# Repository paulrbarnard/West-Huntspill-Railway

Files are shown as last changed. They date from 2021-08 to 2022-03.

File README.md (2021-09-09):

# West-Huntspill-Railway
This is a project for the West Huntspill Model Railway

https://en-gb.facebook.com/pages/category/Arts---Entertainment/West-Huntspill-Railway-246006162152817/

WHR run model live steam and electric locos on their track.

This project was to replace the old signal system with something a little more flexible
The key modules are the SignalBox which provides the control logic with a track display
and the sensor/lights module that detects the trains and switches the signal lights.

PCB layouts are included in the PCB folder in KiCAD format. Parts lists and UK suppliers are in the excel files in the PCB section.

An overview manual is contained in the .docx file

The PCB layouts and code are released free of charge and can be used or modified in any way you like.

No expressed or implied warrenty or gaurentee is made.

If you like the project and make use of it consider a donation to the West Huntspill Model Railway

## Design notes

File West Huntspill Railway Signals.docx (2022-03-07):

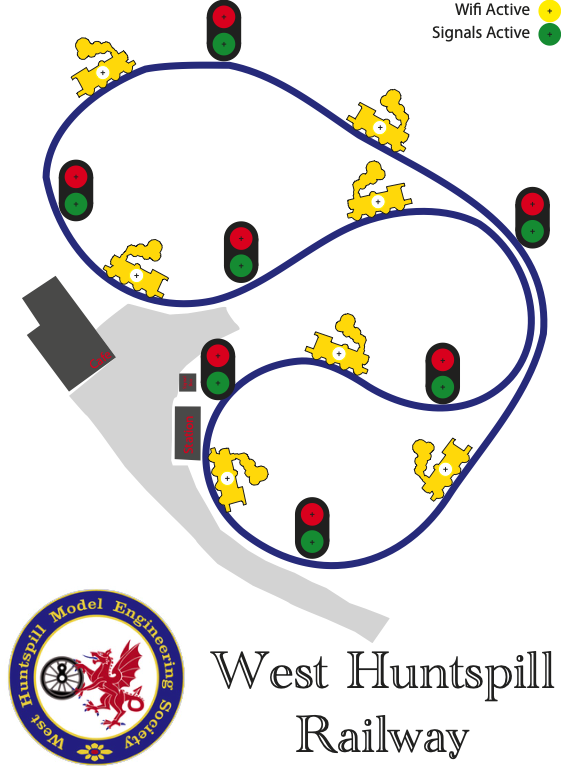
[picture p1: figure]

Signalling

## Signal Box Module

The signal box module is the main controller for the signals around the track. It has two modes of operation, master and slave.

Master mode enables the main processing of the signal box. Messages are received from the sensor modules and the appropriate light changes determined. The light status is then sent to all the sensor modules. In master mode the signal box module can support up to 16 signals.

Slave mode permits the addition of extra track display units showing the location of trains and the state of the signals. When in slave mode the signal box displays the status of the signals and track sections. The number of slave signal box modules is essentially unlimited. Total devices on the network is limited to 200 units.

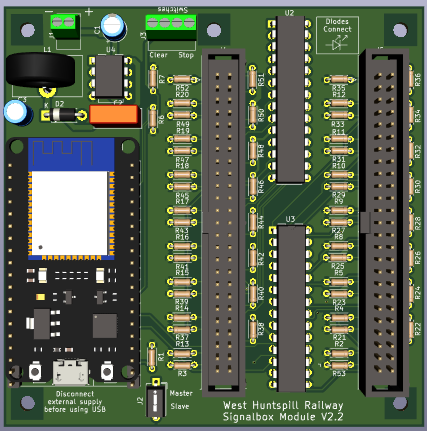
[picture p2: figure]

Figure 1 top view of the signal box pcb

### Power Supply

The signal box module runs from a DC power supply with a voltage between 6 and 24V with a maximum power draw of 1W. Power is connected to the 2 pin screw terminal (J1) on the PCB. Care must be taken to connect the power supply with the correct polarity. Failure to do so can result in damage to the module.

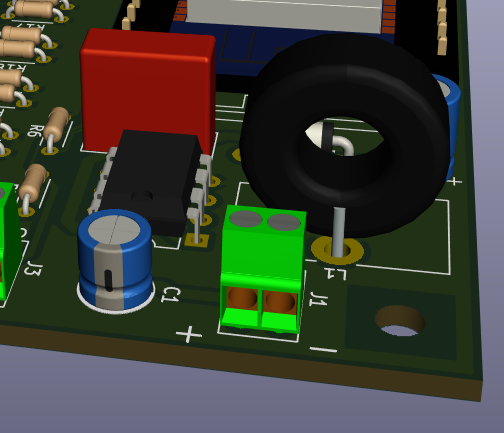
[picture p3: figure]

Figure 2 power connection

### Controls

The signal box module is equipped with two connections for switches to control the signals on the track. Buttons are connected to the 4 pin screw terminal (J3) on the PCB. A “Stop” button, typically a latching button, is used to turn all signals to RED. This would typically be used in an emergency stop situation. A “Clear” button, usually a momentary button, is used to clear all the yellow trains from the track. This is used to clear a “Ghost Train” from a track section if for example it has been removed at the transfer area.

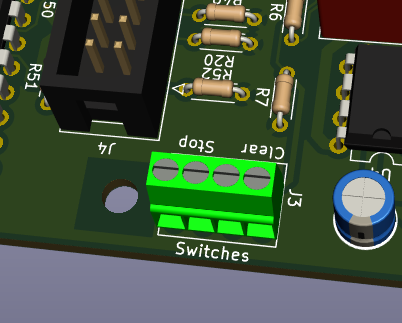
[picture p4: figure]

Figure 3 switch connections

### Indicators

The signal box module has up to 16 red and green LEDs representing the signals on the track. These are matched by up to 16 yellow LEDs indicating an occupied section of track. There is also a yellow “WiFi Active” LED indicating that the signal box module is connected to WiFi and a green “Signals Active” LED indicating that the signal box module is connected to sensor modules and actively controlling the signals. When in Demo mode the Active LED flashes. When in Slave mode the Active LED remains off.

### Typical construction

The typical construction for a signal box module consists of a printed face plate showing the layout and position of the signals with the train LEDs spaced between the signals

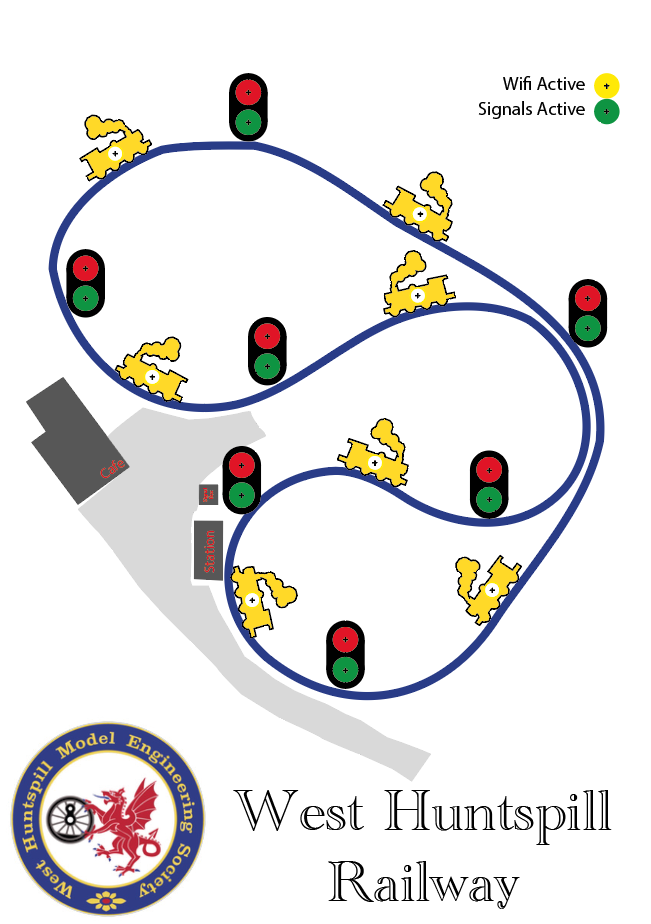
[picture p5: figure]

Figure 4 Typical face plate design

The LEDs are connected via ribbon cable to the signal box module.

### Indicators

The LEDs are connected in groups of three starting at trace one of the ribbon cable. The LED colour sequence is GREEN, RED, YELLOW. The final LED on J4 is YELLOW for the WiFi indication and the final LED on J5 is GREEN for the active indication (note making the WiFi and active LED the same colour would permit a standard cable construction)

The Cathode (+’ve) of the LED connects to the first wire and the Anode (-‘ve) to the next wire in the cable.

The first six traces of the ribbon cable connected to J4 have the indicators for the first track section 0. The first six traces of the ribbon cable connected to J5 have the indicators for section 8.

Populate as many indicators as required for the signals deployed on the track. Fully populating the ribbon cables and leaving the unused indicators inside the signal box case permits simple addition of extra signals indicators in the future.

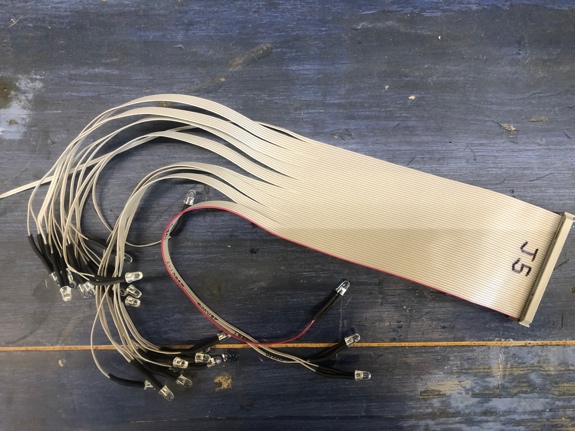
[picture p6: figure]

Figure 5 indicators attached to ribbon cable

### Operation

Power on the signal box module. The WiFi active LED indicator will light when the WiFi is connected. Note: The WiFi can be provided by one of the sensor modules (selectable via jumper on the sensor module). This is suitable for small deployments only and limited to six active devices on the network. For larger layouts an external WiFi network is required. Once WiFi is connected the signal box will listen for sensors to connect. When one or more sensors has connected the signal box module will enter active mode and start controlling the signals. The signals active indicator will light.

Any inactive sensors will be ignored and operation will continue with only the active signals.

It is possible to simply turn the power on for all the sensors and signal box modules to start the signals working.

### Emergency Stop

Press the Stop button and all the signals will be set to RED. Release the Stop button and automatic mode will resume. Any trains that have moved while the Stop mode is enabled will be indicated in their new positions once the Stop button is release.

### Clear Track

Pressing the clear button will remove all the yellow track occupied indicators from the board. Red signals (blocking access to previously occupied track) will remain RED and may be cleared by pressing and releasing the Stop button momentarily.

### Demo Mode

The sensor module has a demo/test mode. This simulates a train travelling around the track switching signals to red and making track occupied. Slave signal box modules and the signals will also indicate the simulated train travel.

Demo mode is started by pressing the stop button and the clear button when the master signal box module is powered on. Hold the clear button down as the train advances around the track until it reaches the final section (when Signal 6 goes red in the example below). Release the clear button to let the signal box know how many sections are included in the demo. The demo mode will continue with the train looping around the track until the stop button is released. When the stop button is released the signal box will enter the normal operating mode.

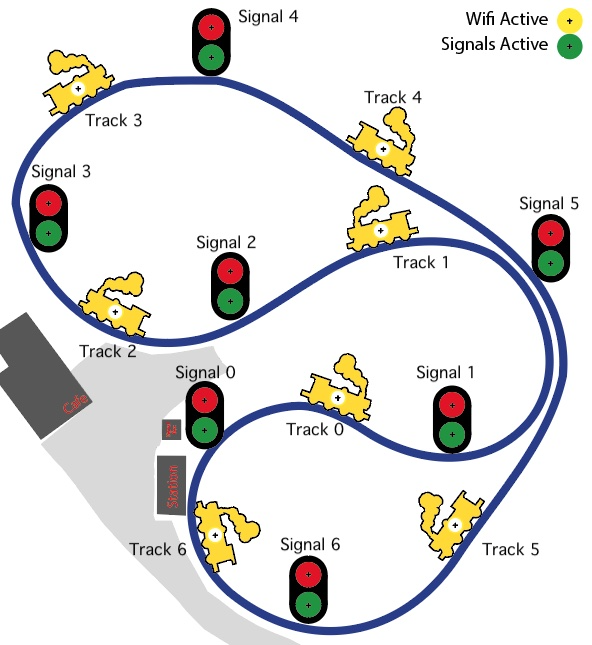
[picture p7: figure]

Figure 6 Indicator detail

## Sensor Module

The sensor module provides multiple functions and great flexibility in layout and use. The sensor module uses an ultra-sonic range sensor to detect the presence of a train. The sensor has a maximum range of 4m and a sensor beam width of 15 degrees. The sensor should be positioned such that a train travelling along the track passes through the ultra-sonic beam. The sensor range is adjustable to eliminate false detection such as from a person walking between the track and the sensor or along the outside of the track.

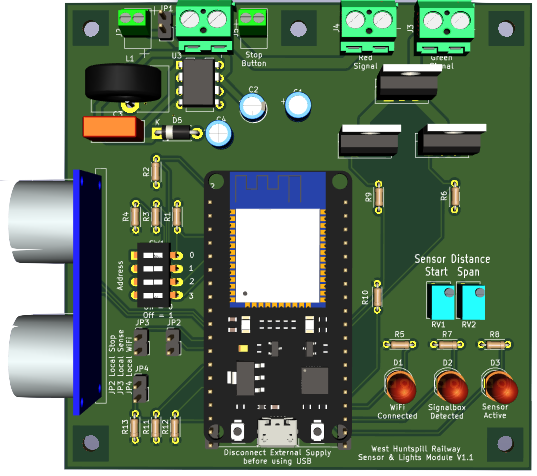
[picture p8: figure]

Figure 7 Sensor module

The sensor module supports a stop button that can be used to turn the signal to red manually. This permits the control of the signal by the station master or steaming bay manager to control departure of trains from the station or to prevent access to the transfer area when trains are being staged. There are two high current capable outputs for connection to the signal lights. The sensor modules are also capable of providing the WiFi network for the system.

### Power Supply

The sensor module has flexible power supply options. It is possible to use different power supplies for the module and the signal lights. This provides more options of lights types, including the possibility of switching motors or solenoids to control functions such as gates, barriers or bells.

If a single supply is to be used a jumper is connected to JP1 and power connected to J1

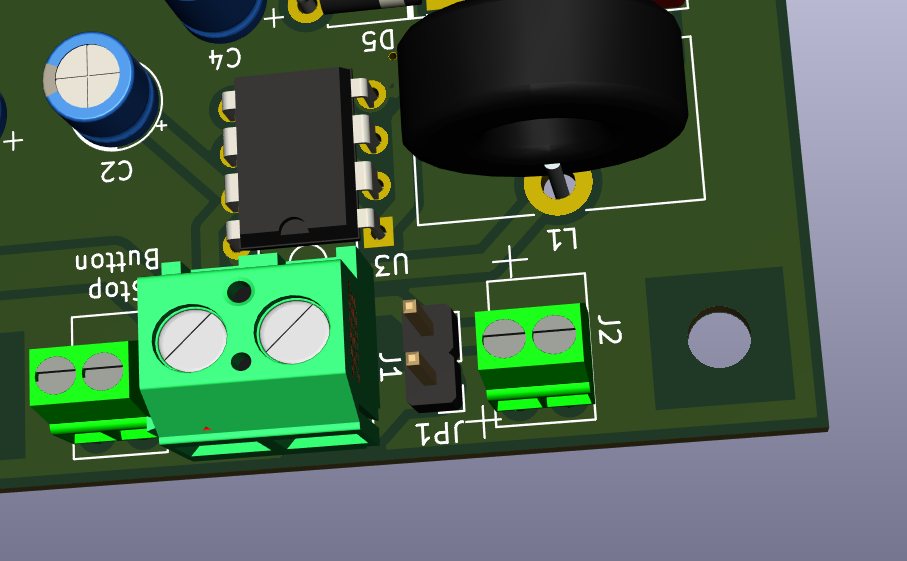
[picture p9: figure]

Figure 8 Power connection

#### Board Power

Connector J2 is used for board power and supports voltages of 6 to 24V DC. Care must be taken to ensure correct polarity of the power connection. Incorrect connection can damage the sensor module.

#### Signal Power

Connector J1 is used for the signal lights power and supports voltages from 6 to 60V. The sensor module switches can handle 50A maximum but require additional heat sinks for currents over 10A. If inductive loads (motors, solenoids, relays etc) are connect then the protection diode D4 (DSSK50-01A) must be fitted.

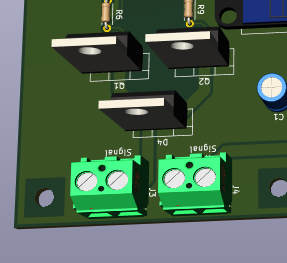
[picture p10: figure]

Figure 9 Location of protection diode

Important! If JP1 is fitted the signal power must not exceed 24V or damage to the sensor module will occur.

### Signal Connections

The signal lights are connected to J3 (green) and J4 (red). If LED lights are used ensure the polarity of connection is correct.

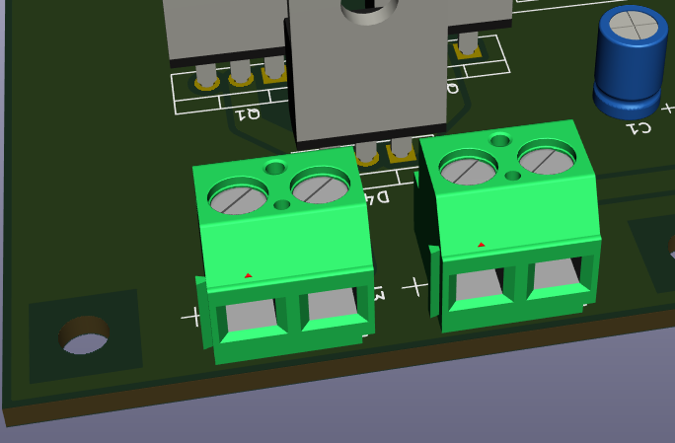
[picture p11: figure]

Figure 10 Signal light connectors

### Stop button

An optional stop button can be connected to the sensor module. This permits the manual control of the signal from the signal location. A typical use is at the station where a stop button can be used by the station master to control the departure of trains. Wire connections to the stop button should be limited in length to ensure reliability. As a rule of thumb 10m should be OK. In the case where the stop button needs to be at a greater distance (possibly at the transfer area) an additional sensor module can be used as a remote stop button Configuration

#### Address

Each sensor module needs to be assigned an address. This corresponds to its position in the signal sequence around the track, see Figure 6 Indicator detail for a typical addressing sequence for a track.

Addresses are set using SW1

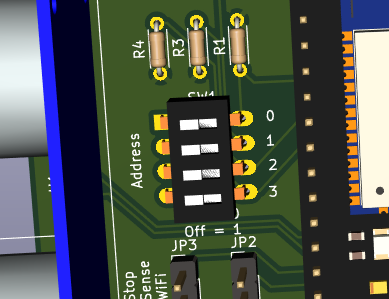
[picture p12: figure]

Figure 11 Address switch showing set to address 15

The following table shows the switch settings for all possible addresses.

Sensor | SW1-0 | SW1-1 | SW1-2 | SW1-3
0 | ON | ON | ON | ON
1 | OFF | ON | ON | ON
2 | ON | OFF | ON | ON
3 | OFF | OFF | ON | ON
4 | ON | ON | OFF | ON
5 | OFF | ON | OFF | ON
6 | ON | OFF | OFF | ON
7 | OFF | OFF | OFF | ON
8 | ON | ON | ON | OFF
9 | OFF | ON | ON | OFF
10 | ON | OFF | ON | OFF
11 | OFF | OFF | ON | OFF
12 | ON | ON | OFF | OFF
13 | OFF | ON | OFF | OFF
14 | ON | OFF | OFF | OFF
15 | OFF | OFF | OFF | OFF

When using multiple sensor modules for a single section of track set all the modules to the same address

### Local Jumpers

The three local jumpers permit configuration of the board characteristics.

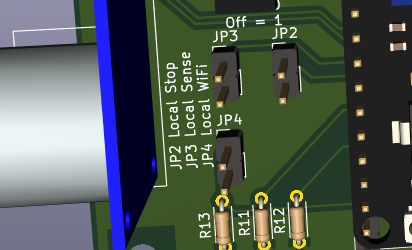
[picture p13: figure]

Figure 12 Local configuration jumpers

#### Local WiFi

When JP4 is shorted the sensor module will create a WiFi network for the signals. Only one sensor module, usually the one closest to the centre of the area, is configured to provide the WiFi network.

Note: Local WiFi only supports six connected devices. For larger networks of devices and external WiFi device is required.

#### Local Stop

JP2 is used to configure the operation of the stop switch. When the jumper is not fitted the presence of a train on the track is determined by the train sensor. When JP2 is shorted releasing the stop switch will force clear the track. Typical use of the forced clear option is at the Steaming Bay where trains are removed from the track. Releasing the stop button will clear the track and set the signals to green. Alternatively at the Station, configured without the short, releasing the stop button will cause the red signal to flash if a train is still occupying the track after the light. This lets the station master know that he/she has released the stop but it is not safe for the train to depart.

Note: an additional sensor module can be used to support the stop button. The signal light switching will also function on the additional module enabling local tally lights to be connected to the remote sensor module. This is useful if the main signal lights are not visible from the stop button location.

#### Local Sense

JP3 is used to disable the sensor distance settings on the board. When shorted the sensor will take the sensor range settings sent by the signal box. This permits the use of the WHRDisplay application to configure the sensor settings.

### Train Sensor setup

The ultra-sonic train sensor can be configured to avoid false detection. Two adjustment screws are provided.

RV1 is used to set the minimum detection distance. RV2 sets the span of the detection range.

Alternatively the WHRDisplay application can be used with the sensor configured for remote settings.

To adjust the range position a board between the train sensor and the track so that the board is a few centimetres closer to the sensor than any part of the train will travel. The widest part of the train is likely the legs of the driver or passengers.

Figure 13 Sensor setup method

Turn the sensor screw until the sensor active LED on the sensor module lights up. You might need to wind the screw fully one way then reverse the direction to find the detection point. Fully anti clock wise is the minimum distance. 10 full turns are required to go from end to end of the adjustment.

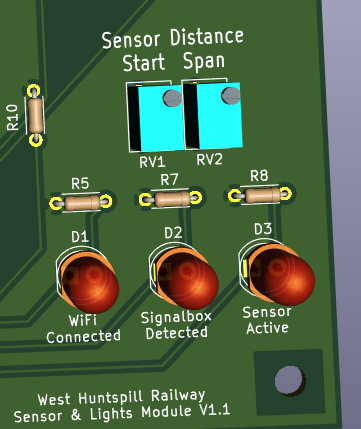
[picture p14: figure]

Figure 14 Sensor adjustment screws and sensor active LED

Reposition the board to the outside of the track and adjust the span screw until the sensor active LED just changes state.

Check the settings are correct by moving the board from the sensor position to the far side of the track and watch the sensor active LED. It should light when the board is positioned anywhere where the train is expected to travel. Walk through the sensor beam on both the inside and outside of the track to ensure that the sensor does not trigger.

Note: The sensor only registers the closest thing to the sensor. If a person or other object is blocking the path between the sensor and the track the sensor will not activate when a train passes.

#### WHRDisplay application

An iPhone, iPad and macOS application is available which displays the current track light status and displays the messages sent by the sensor modules. When adjustments to the distance are made these can be seen on the application.

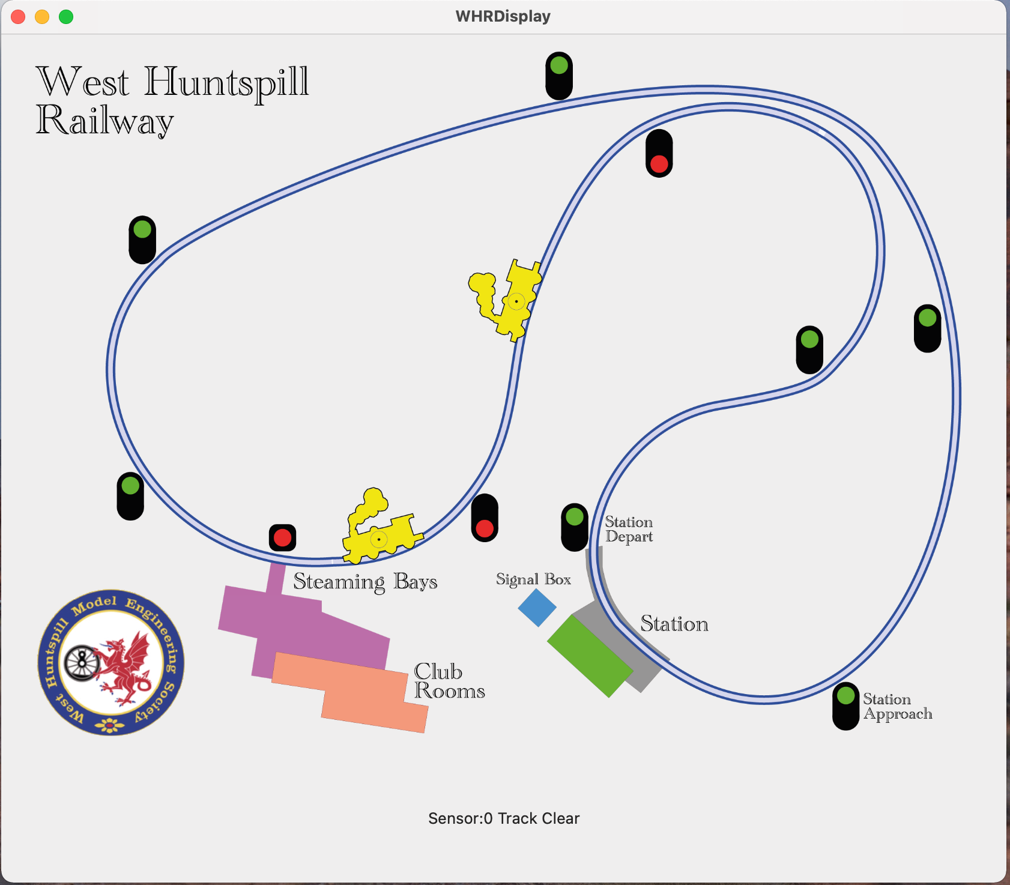
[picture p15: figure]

Figure 15 WHRDisplay application

## TP-Link Exterior WiFi

For full coverage of the WHR site an external WiFi device is provided. This is based on a TP-Link Omada Outdoor access point. The outdoor part should be mounted on the roof of the signal box or at some other convenient location. Coverage area is an approximately 200m radius. The unit has an indoor box that provides power and the network connectivity. Note: the indoor unit is a custom device built using the TP-Link power over ethernet adaptor and the main board from an GL-iNet Smart router, together with a 5V power supply. The indoor unit is installed in a 3D printed box.

The indoor unit should be located close to a Mains 240V supply. An ethernet cable connects the indoor and outdoor units. Ethernet cables up to 100m are supported.

Plugging a 4G or 5G USB dongle or smart phone supporting tethering in to the side of the indoor unit can enable the provision of wide area network connectivity for the site. This might be useful at a future date. If required at any time please contact Paul Barnard to configure a public access SSID for the network.

## Information

The source code and PCB layouts (KiCAD) for the project are available on GitHub

https://github.com/paulrbarnard/West-Huntspill-Railway.git

The PCB are laid out for ESP32 DevKitC V4. Full parts list and UK based supplier information is contained in the PCB design documents.

The ESP board will be damaged if the USB is connected at the same time as the board power supply. The board power supply must be disconnected before using the USB to program the ESP32. The ESP32DevKit devices are socketed and can be removed from the main PCB for reprogramming to eliminate the need to disconnect wiring on site.

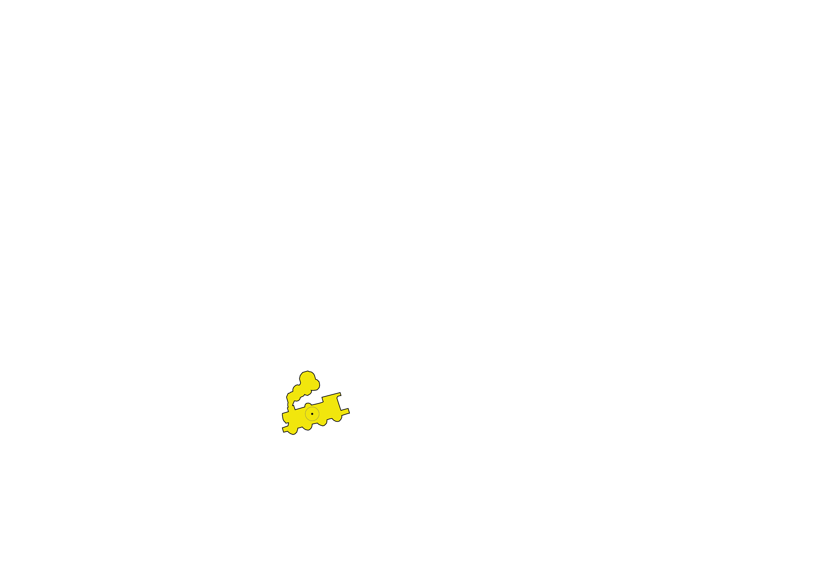
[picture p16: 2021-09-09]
Face Plate Artwork/3x/Train3@3x.png

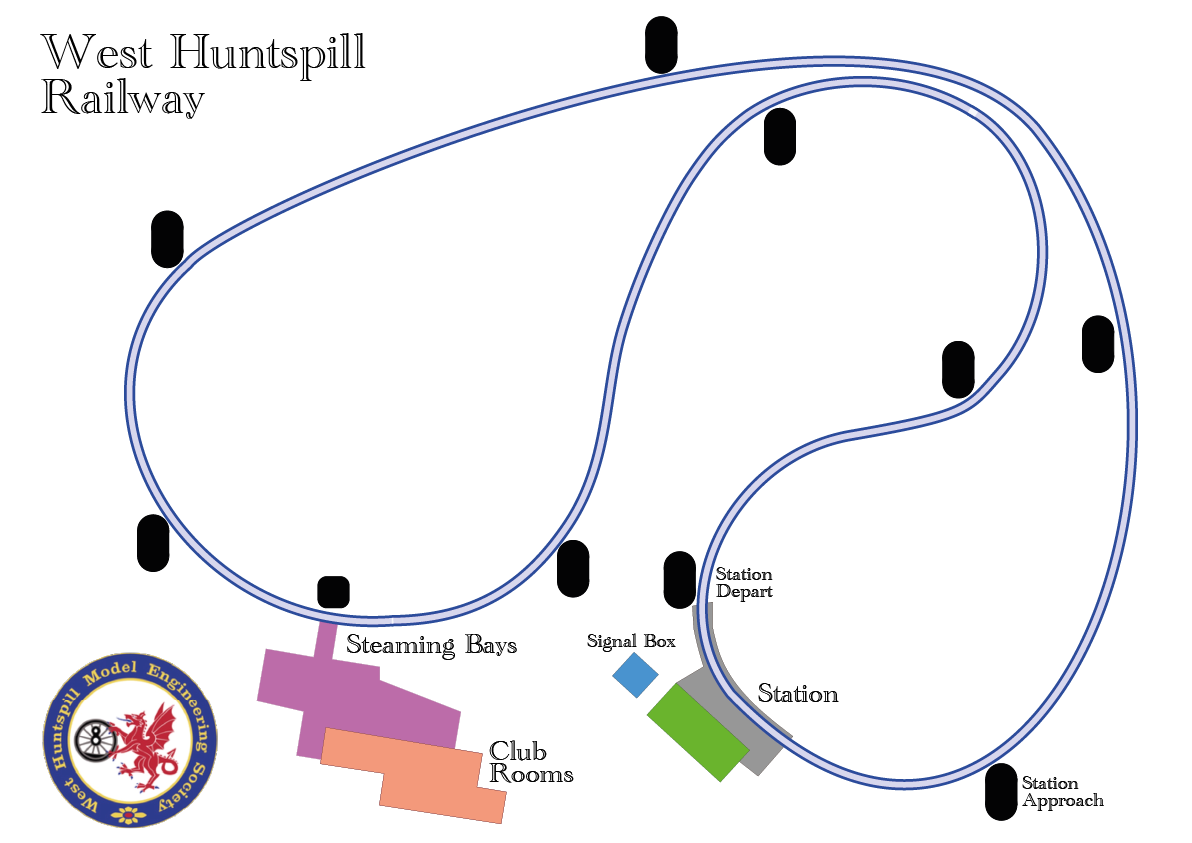
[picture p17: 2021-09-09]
Face Plate Artwork/1x/background.png

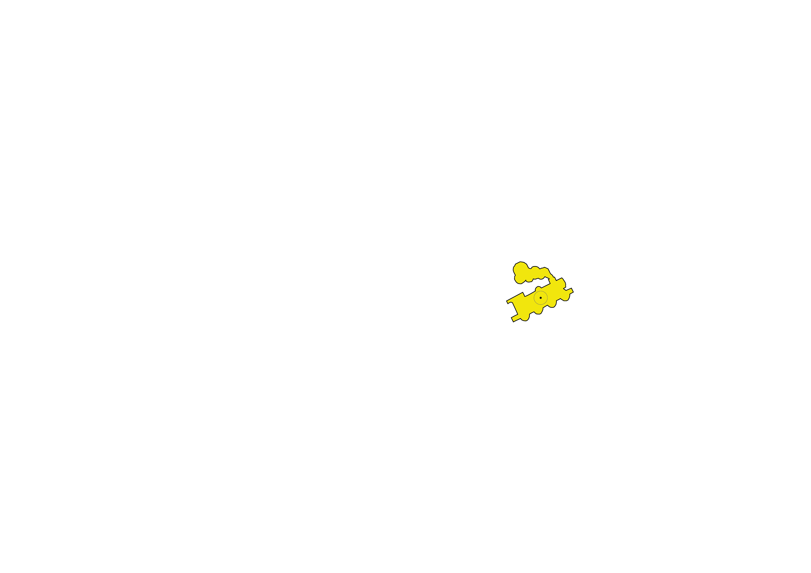
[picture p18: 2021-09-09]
Face Plate Artwork/3x/Train0@3x.png

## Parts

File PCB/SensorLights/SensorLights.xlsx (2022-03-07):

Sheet: BOM
Reference | Value | Footprint | Datasheet | Source
C2 | 100uF | Capacitor_THT:CP_Radial_D5.0mm_P2.00mm | https://docs.rs-online.com/bcd8/0900766b814894c5.pdf | https://uk.rs-online.com/web/p/aluminium-capacitors/3150962/
R1 | 10K | Resistor_THT:R_Axial_DIN0204_L3.6mm_D1.6mm_P5.08mm_Horizontal | https://docs.rs-online.com/76ca/0900766b8157ae01.pdf | https://uk.rs-online.com/web/p/through-hole-fixed-resistors/7077745/
R11 | 10K | Resistor_THT:R_Axial_DIN0204_L3.6mm_D1.6mm_P5.08mm_Horizontal | https://docs.rs-online.com/76ca/0900766b8157ae01.pdf | https://uk.rs-online.com/web/p/through-hole-fixed-resistors/7077745/
R12 | 10K | Resistor_THT:R_Axial_DIN0204_L3.6mm_D1.6mm_P5.08mm_Horizontal | https://docs.rs-online.com/76ca/0900766b8157ae01.pdf | https://uk.rs-online.com/web/p/through-hole-fixed-resistors/7077745/
R13 | 10K | Resistor_THT:R_Axial_DIN0204_L3.6mm_D1.6mm_P5.08mm_Horizontal | https://docs.rs-online.com/76ca/0900766b8157ae01.pdf | https://uk.rs-online.com/web/p/through-hole-fixed-resistors/7077745/
R2 | 10K | Resistor_THT:R_Axial_DIN0204_L3.6mm_D1.6mm_P5.08mm_Horizontal | https://docs.rs-online.com/76ca/0900766b8157ae01.pdf | https://uk.rs-online.com/web/p/through-hole-fixed-resistors/7077745/
R3 | 10K | Resistor_THT:R_Axial_DIN0204_L3.6mm_D1.6mm_P5.08mm_Horizontal | https://docs.rs-online.com/76ca/0900766b8157ae01.pdf | https://uk.rs-online.com/web/p/through-hole-fixed-resistors/7077745/
R4 | 10K | Resistor_THT:R_Axial_DIN0204_L3.6mm_D1.6mm_P5.08mm_Horizontal | https://docs.rs-online.com/76ca/0900766b8157ae01.pdf | https://uk.rs-online.com/web/p/through-hole-fixed-resistors/7077745/
R6 | 10K | Resistor_THT:R_Axial_DIN0204_L3.6mm_D1.6mm_P5.08mm_Horizontal | https://docs.rs-online.com/76ca/0900766b8157ae01.pdf | https://uk.rs-online.com/web/p/through-hole-fixed-resistors/7077745/
R9 | 10K | Resistor_THT:R_Axial_DIN0204_L3.6mm_D1.6mm_P5.08mm_Horizontal | https://docs.rs-online.com/76ca/0900766b8157ae01.pdf | https://uk.rs-online.com/web/p/through-hole-fixed-resistors/7077745/
C3 | 10nF | Capacitor_THT:C_Rect_L10.0mm_W4.0mm_P7.50mm_MKS4 | https://docs.rs-online.com/9793/0900766b814700cb.pdf | https://uk.rs-online.com/web/p/polypropylene-film-capacitors/8961512/
R5 | 1K2 | Resistor_THT:R_Axial_DIN0204_L3.6mm_D1.6mm_P5.08mm_Horizontal | https://docs.rs-online.com/ce35/0900766b8157adf1.pdf | https://uk.rs-online.com/web/p/through-hole-fixed-resistors/7077678/
R8 | 1K2 | Resistor_THT:R_Axial_DIN0204_L3.6mm_D1.6mm_P5.08mm_Horizontal | https://docs.rs-online.com/ce35/0900766b8157adf1.pdf | https://uk.rs-online.com/web/p/through-hole-fixed-resistors/7077678/
D5 | 1N5819RL | Diode_THT:D_DO-41_SOD81_P7.62mm_Horizontal | https://docs.rs-online.com/6961/0900766b80da3e32.pdf | https://uk.rs-online.com/web/p/schottky-diodes-rectifiers/6870754/
R10 | 470R | Resistor_THT:R_Axial_DIN0204_L3.6mm_D1.6mm_P5.08mm_Horizontal | https://docs.rs-online.com/b9c3/0900766b8157ade8.pdf | https://uk.rs-online.com/web/p/through-hole-fixed-resistors/7077647/
R7 | 470R | Resistor_THT:R_Axial_DIN0204_L3.6mm_D1.6mm_P5.08mm_Horizontal | https://docs.rs-online.com/b9c3/0900766b8157ade8.pdf | https://uk.rs-online.com/web/p/through-hole-fixed-resistors/7077647/
L1 | 47uH | Inductor_THT:L_Toroid_Vertical_L14.7mm_W8.6mm_P5.58mm_Pulse_KM-1 | https://docs.rs-online.com/24ef/0900766b81505716.pdf | https://uk.rs-online.com/web/p/leaded-inductors/1048418/
C1 | 68uF | Capacitor_THT:C_Radial_D4.0mm_H7.0mm_P1.50mm | https://docs.rs-online.com/f424/0900766b80becf93.pdf | https://uk.rs-online.com/web/p/aluminium-capacitors/0572312/
C4 | 68uF | Capacitor_THT:C_Radial_D4.0mm_H7.0mm_P1.50mm | https://docs.rs-online.com/f424/0900766b80becf93.pdf | https://uk.rs-online.com/web/p/aluminium-capacitors/0572312/
SW1 | Address | Package_DIP:DIP_SW-8_W7.62mm_LongPads | https://docs.rs-online.com/dee5/0900766b813ebdbf.pdf | https://uk.rs-online.com/web/p/dip-sip-switches/0342102/
J2 | Board Power | Pauls Parts:2WayScrewTerminal_2.54 | https://docs.rs-online.com/90f4/0900766b8157c7e9.pdf | https://uk.rs-online.com/web/p/pcb-terminal-blocks/7901098/
D4 | DSSK50-01A | Package_TO_SOT_THT:TO-220-3_Vertical | https://docs.rs-online.com/9374/0900766b80a38b02.pdf | https://uk.rs-online.com/web/p/schottky-diodes-rectifiers/0192994/
U2 | ESP32_DevKit_V4 | ESP32_DevKit_V4:esp32_devkit_v4 | https://docs.espressif.com/projects/esp-idf/en/latest/esp32/hw-reference/esp32/get-started-devkitc.html | https://www.amazon.co.uk/Dorhea-ESP32-DevKitC-Development-ESP32-WROOM-32U-Amplifier/dp/B08T5RBCXS
D2 | Green | LED_THT:LED_D5.0mm | https://docs.rs-online.com/5a16/0900766b8162d8a7.pdf | https://uk.rs-online.com/web/p/leds/1682428/
J3 | Green Signal | Connector:2WayTerminalStrip_5mm | https://docs.rs-online.com/0623/0900766b8157c7d5.pdf | https://uk.rs-online.com/web/p/pcb-terminal-blocks/7901064/
U1 | HC-SR04 | Sensor_Distance:HC-SR04 | https://docs.rs-online.com/8bc5/A700000007388293.pdf | https://uk.rs-online.com/web/p/bbc-micro-bit-add-ons/2153181/
JP1 | Jumper | Connector_PinHeader_2.54mm:PinHeader_1x02_P2.54mm_Vertical | https://docs.rs-online.com/8109/A700000007648145.pdf | https://uk.rs-online.com/web/p/pcb-headers/2518086/
U3 | LM2675N-5 | Package_DIP:DIP-8_W7.62mm | http://www.ti.com/lit/ds/symlink/lm2675.pdf | https://uk.farnell.com/texas-instruments/lm2675n-5-0-nopb/ic-dc-dc-converter-1a/dp/3122905?st=lm2675n-5
JP3 | Local Sense | Connector_PinHeader_2.54mm:PinHeader_1x02_P2.54mm_Vertical | https://docs.rs-online.com/8109/A700000007648145.pdf | https://uk.rs-online.com/web/p/pcb-headers/2518086/
JP2 | Local Stop | Connector_PinHeader_2.54mm:PinHeader_1x02_P2.54mm_Vertical | https://docs.rs-online.com/8109/A700000007648145.pdf | https://uk.rs-online.com/web/p/pcb-headers/2518086/
J5 | Manual Stop | Pauls Parts:2WayScrewTerminal_2.54 | https://docs.rs-online.com/90f4/0900766b8157c7e9.pdf | https://uk.rs-online.com/web/p/pcb-terminal-blocks/7901098/
D3 | Red | LED_THT:LED_D5.0mm | https://docs.rs-online.com/436b/0900766b8162d8d6.pdf | https://uk.rs-online.com/web/p/leds/1682471/
J4 | Red Signal | Connector:2WayTerminalStrip_5mm | https://docs.rs-online.com/0623/0900766b8157c7d5.pdf | https://uk.rs-online.com/web/p/pcb-terminal-blocks/7901064/
Q1 | RFP50N06LE | Package_TO_SOT_THT:TO-220-3_Vertical | https://docs.rs-online.com/44a2/0900766b8003167d.pdf | https://uk.rs-online.com/web/p/mosfets/3257625/
Q2 | RFP50N06LE | Package_TO_SOT_THT:TO-220-3_Vertical | https://docs.rs-online.com/44a2/0900766b8003167d.pdf | https://uk.rs-online.com/web/p/mosfets/3257625/
J1 | Signal Power | Connector:2WayTerminalStrip_5mm | https://docs.rs-online.com/0623/0900766b8157c7d5.pdf | https://uk.rs-online.com/web/p/pcb-terminal-blocks/7901064/
JP4 | Spare | Connector_PinHeader_2.54mm:PinHeader_1x02_P2.54mm_Vertical | https://docs.rs-online.com/8109/A700000007648145.pdf | https://uk.rs-online.com/web/p/pcb-headers/2518086/
D1 | Yellow | LED_THT:LED_D5.0mm | https://docs.rs-online.com/f8c6/0900766b8162d8d7.pdf | https://uk.rs-online.com/web/p/leds/1682378/
Non board parts
 | 2.4GHz Antenna |  |  | https://www.ebay.co.uk/itm/202185734795?chn=ps&mkevt=1&mkcid=28&var=502163080733

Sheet: Grouped
Reference | Quantity |  |  | Value | Footprint | Datasheet | Source
C1 C4 | 2 |  | 0 | 68uF | Capacitor_THT:C_Radial_D4.0mm_H7.0mm_P1.50mm | https://docs.rs-online.com/f424/0900766b80becf93.pdf | https://uk.rs-online.com/web/p/aluminium-capacitors/0572312/
C2 | 1 |  | 0 | 100uF | Capacitor_THT:CP_Radial_D5.0mm_P2.00mm | https://docs.rs-online.com/bcd8/0900766b814894c5.pdf | https://uk.rs-online.com/web/p/aluminium-capacitors/3150962/
C3 | 1 |  | 5 | 10nF | Capacitor_THT:C_Rect_L10.0mm_W4.0mm_P7.50mm_MKS4 | https://docs.rs-online.com/9793/0900766b814700cb.pdf | https://uk.rs-online.com/web/p/polypropylene-film-capacitors/8961512/
D1 | 1 |  | 0 | Yellow | LED_THT:LED_D5.0mm | https://docs.rs-online.com/f8c6/0900766b8162d8d7.pdf | https://uk.rs-online.com/web/p/leds/1682378/
D2 | 1 |  | 0 | Green | LED_THT:LED_D5.0mm | https://docs.rs-online.com/5a16/0900766b8162d8a7.pdf | https://uk.rs-online.com/web/p/leds/1682428/
D3 | 1 |  | 0 | Red | LED_THT:LED_D5.0mm | https://docs.rs-online.com/436b/0900766b8162d8d6.pdf | https://uk.rs-online.com/web/p/leds/1682471/
D4 | 1 |  | 12 | DSSK50-01A | Package_TO_SOT_THT:TO-220-3_Vertical | https://docs.rs-online.com/9374/0900766b80a38b02.pdf | https://uk.rs-online.com/web/p/schottky-diodes-rectifiers/0192994/
D5 | 1 |  | 0 | 1N5819RL | Diode_THT:D_DO-41_SOD81_P7.62mm_Horizontal | https://docs.rs-online.com/6961/0900766b80da3e32.pdf | https://uk.rs-online.com/web/p/schottky-diodes-rectifiers/6870754/
J1 | 1 |  | 0 | Signal Power | Connector:2WayTerminalStrip_5mm | https://docs.rs-online.com/0623/0900766b8157c7d5.pdf | https://uk.rs-online.com/web/p/pcb-terminal-blocks/7901064/
J2 | 1 |  | 7 | Board Power | Pauls Parts:2WayScrewTerminal_2.54 | https://docs.rs-online.com/90f4/0900766b8157c7e9.pdf | https://uk.rs-online.com/web/p/pcb-terminal-blocks/7901098/
J3 | 1 |  | 7 | Green Signal | Connector:2WayTerminalStrip_5mm | https://docs.rs-online.com/0623/0900766b8157c7d5.pdf | https://uk.rs-online.com/web/p/pcb-terminal-blocks/7901064/
J4 | 1 |  | 7 | Red Signal | Connector:2WayTerminalStrip_5mm | https://docs.rs-online.com/0623/0900766b8157c7d5.pdf | https://uk.rs-online.com/web/p/pcb-terminal-blocks/7901064/
J5 | 1 |  | 7 | Manual Stop | Pauls Parts:2WayScrewTerminal_2.54 | https://docs.rs-online.com/90f4/0900766b8157c7e9.pdf | https://uk.rs-online.com/web/p/pcb-terminal-blocks/7901098/
JP1 | 1 |  | 0 | Jumper | Connector_PinHeader_2.54mm:PinHeader_1x02_P2.54mm_Vertical | https://docs.rs-online.com/8109/A700000007648145.pdf | https://uk.rs-online.com/web/p/pcb-headers/2518086/
JP2 | 1 |  | 0 | Local Stop | Connector_PinHeader_2.54mm:PinHeader_1x02_P2.54mm_Vertical | https://docs.rs-online.com/8109/A700000007648145.pdf | https://uk.rs-online.com/web/p/pcb-headers/2518086/
JP3 | 1 |  | 0 | Local Sense | Connector_PinHeader_2.54mm:PinHeader_1x02_P2.54mm_Vertical | https://docs.rs-online.com/8109/A700000007648145.pdf | https://uk.rs-online.com/web/p/pcb-headers/2518086/
JP4 | 1 |  | 0 | Spare | Connector_PinHeader_2.54mm:PinHeader_1x02_P2.54mm_Vertical | https://docs.rs-online.com/8109/A700000007648145.pdf | https://uk.rs-online.com/web/p/pcb-headers/2518086/
L1 | 1 |  | 5 | 47uH | Inductor_THT:L_Toroid_Vertical_L14.7mm_W8.6mm_P5.58mm_Pulse_KM-1 | https://docs.rs-online.com/24ef/0900766b81505716.pdf | https://uk.rs-online.com/web/p/leaded-inductors/1048418/
Q1 Q2 | 2 |  | 14 | RFP50N06LE | Package_TO_SOT_THT:TO-220-3_Vertical | https://docs.rs-online.com/44a2/0900766b8003167d.pdf | https://uk.rs-online.com/web/p/mosfets/3257625/
R1 R2 R3 R4 R6 R9 R11 R12 R13 | 9 |  | 61 | 10K | Resistor_THT:R_Axial_DIN0204_L3.6mm_D1.6mm_P5.08mm_Horizontal | https://docs.rs-online.com/76ca/0900766b8157ae01.pdf | https://uk.rs-online.com/web/p/through-hole-fixed-resistors/1251153/?searchHistory=%7B%22enabled%22%3Atrue%7D
R5 R8 | 2 |  | 12 | 1K2 | Resistor_THT:R_Axial_DIN0204_L3.6mm_D1.6mm_P5.08mm_Horizontal | https://docs.rs-online.com/ce35/0900766b8157adf1.pdf | https://uk.rs-online.com/web/p/through-hole-fixed-resistors/0135853/?searchHistory=%7B%22enabled%22%3Atrue%7D
R7 R10 | 2 |  | 10 | 470R | Resistor_THT:R_Axial_DIN0204_L3.6mm_D1.6mm_P5.08mm_Horizontal | https://docs.rs-online.com/b9c3/0900766b8157ade8.pdf | https://uk.rs-online.com/web/p/through-hole-fixed-resistors/0135831/?searchHistory=%7B%22enabled%22%3Atrue%7D
SW1 | 1 |  | 7 | Address | Package_DIP:DIP_SW-8_W7.62mm_LongPads | https://docs.rs-online.com/dee5/0900766b813ebdbf.pdf | https://uk.rs-online.com/web/p/dip-sip-switches/0342102/
U1 | 1 |  | 3 | HC-SR04 | Sensor_Distance:HC-SR04 | https://docs.rs-online.com/8bc5/A700000007388293.pdf | https://uk.rs-online.com/web/p/bbc-micro-bit-add-ons/2153181/
U2 | 1 |  | 0 | ESP32_DevKit_V4 | ESP32_DevKit_V4:esp32_devkit_v4 | https://docs.espressif.com/projects/esp-idf/en/latest/esp32/hw-reference/esp32/get-started-devkitc.html | https://www.amazon.co.uk/Dorhea-ESP32-DevKitC-Development-ESP32-WROOM-32U-Amplifier/dp/B08T5RBCXS
U3 | 1 |  | 5 | LM2675N-5 | Package_DIP:DIP-8_W7.62mm | http://www.ti.com/lit/ds/symlink/lm2675.pdf | https://uk.farnell.com/texas-instruments/lm2675n-5-0-nopb/ic-dc-dc-converter-1a/dp/3122905?st=lm2675n-5
Number of Sensor boards | 7
 | Quantity | available | required | Value | Footprint | Datasheet | Source
 | 14 | 30 | 0 | 68uF | Capacitor_THT:C_Radial_D4.0mm_H7.0mm_P1.50mm | https://docs.rs-online.com/f424/0900766b80becf93.pdf | https://uk.rs-online.com/web/p/aluminium-capacitors/0572312/
 | 7 | 30 | 0 | 100uF | Capacitor_THT:CP_Radial_D5.0mm_P2.00mm | https://docs.rs-online.com/bcd8/0900766b814894c5.pdf | https://uk.rs-online.com/web/p/aluminium-capacitors/3150962/
 | 7 | 2 | 5 | 10nF | Capacitor_THT:C_Rect_L10.0mm_W4.0mm_P7.50mm_MKS4 | https://docs.rs-online.com/9793/0900766b814700cb.pdf | https://uk.rs-online.com/web/p/polypropylene-film-capacitors/8961512/
 | 7 | 7 | 0 | Yellow | LED_THT:LED_D5.0mm | https://docs.rs-online.com/f8c6/0900766b8162d8d7.pdf | https://uk.rs-online.com/web/p/leds/1682378/
 | 7 | 10 | 0 | Green | LED_THT:LED_D5.0mm | https://docs.rs-online.com/5a16/0900766b8162d8a7.pdf | https://uk.rs-online.com/web/p/leds/1682428/
 | 7 | 10 | 0 | Red | LED_THT:LED_D5.0mm | https://docs.rs-online.com/436b/0900766b8162d8d6.pdf | https://uk.rs-online.com/web/p/leds/1682471/
 | 7 | 0 | 12 | DSSK50-01A | Package_TO_SOT_THT:TO-220-3_Vertical | https://docs.rs-online.com/9374/0900766b80a38b02.pdf | https://uk.rs-online.com/web/p/schottky-diodes-rectifiers/0192994/
 | 7 | 30 | 0 | 1N5819RL | Diode_THT:D_DO-41_SOD81_P7.62mm_Horizontal | https://docs.rs-online.com/6961/0900766b80da3e32.pdf | https://uk.rs-online.com/web/p/schottky-diodes-rectifiers/6870754/
 | 7 | 50 | 0 | Signal Power | Connector:2WayTerminalStrip_5mm | https://docs.rs-online.com/0623/0900766b8157c7d5.pdf | https://uk.rs-online.com/web/p/pcb-terminal-blocks/7901064/
 | 7 | 0 | 7 | Board Power | Pauls Parts:2WayScrewTerminal_2.54 | https://docs.rs-online.com/90f4/0900766b8157c7e9.pdf | https://uk.rs-online.com/web/p/pcb-terminal-blocks/7901098/
 | 7 | 0 | 7 | Green Signal | Connector:2WayTerminalStrip_5mm | https://docs.rs-online.com/0623/0900766b8157c7d5.pdf | https://uk.rs-online.com/web/p/pcb-terminal-blocks/7901064/
 | 7 | 0 | 7 | Red Signal | Connector:2WayTerminalStrip_5mm | https://docs.rs-online.com/0623/0900766b8157c7d5.pdf | https://uk.rs-online.com/web/p/pcb-terminal-blocks/7901064/
 | 7 | 0 | 7 | Manual Stop | Pauls Parts:2WayScrewTerminal_2.54 | https://docs.rs-online.com/90f4/0900766b8157c7e9.pdf | https://uk.rs-online.com/web/p/pcb-terminal-blocks/7901098/
 | 7 | 30 | 0 | Jumper | Connector_PinHeader_2.54mm:PinHeader_1x02_P2.54mm_Vertical | https://docs.rs-online.com/8109/A700000007648145.pdf | https://uk.rs-online.com/web/p/pcb-headers/2518086/
 | 7 | 30 | 0 | Local Stop | Connector_PinHeader_2.54mm:PinHeader_1x02_P2.54mm_Vertical | https://docs.rs-online.com/8109/A700000007648145.pdf | https://uk.rs-online.com/web/p/pcb-headers/2518086/
 | 7 | 30 | 0 | Local Sense | Connector_PinHeader_2.54mm:PinHeader_1x02_P2.54mm_Vertical | https://docs.rs-online.com/8109/A700000007648145.pdf | https://uk.rs-online.com/web/p/pcb-headers/2518086/
 | 7 | 30 | 0 | Spare | Connector_PinHeader_2.54mm:PinHeader_1x02_P2.54mm_Vertical | https://docs.rs-online.com/8109/A700000007648145.pdf | https://uk.rs-online.com/web/p/pcb-headers/2518086/
 | 7 | 2 | 5 | 47uH | Inductor_THT:L_Toroid_Vertical_L14.7mm_W8.6mm_P5.58mm_Pulse_KM-1 | https://docs.rs-online.com/24ef/0900766b81505716.pdf | https://uk.rs-online.com/web/p/leaded-inductors/1048418/
 | 14 | 0 | 14 | RFP50N06LE | Package_TO_SOT_THT:TO-220-3_Vertical | https://docs.rs-online.com/44a2/0900766b8003167d.pdf | https://uk.rs-online.com/web/p/mosfets/3257625/
 | 63 | 2 | 61 | 10K | Resistor_THT:R_Axial_DIN0204_L3.6mm_D1.6mm_P5.08mm_Horizontal | https://docs.rs-online.com/76ca/0900766b8157ae01.pdf | https://uk.rs-online.com/web/p/through-hole-fixed-resistors/1251153/?searchHistory=%7B%22enabled%22%3Atrue%7D
 | 14 | 2 | 12 | 1K2 | Resistor_THT:R_Axial_DIN0204_L3.6mm_D1.6mm_P5.08mm_Horizontal | https://docs.rs-online.com/ce35/0900766b8157adf1.pdf | https://uk.rs-online.com/web/p/through-hole-fixed-resistors/0135853/?searchHistory=%7B%22enabled%22%3Atrue%7D
 | 14 | 4 | 10 | 470R | Resistor_THT:R_Axial_DIN0204_L3.6mm_D1.6mm_P5.08mm_Horizontal | https://docs.rs-online.com/b9c3/0900766b8157ade8.pdf | https://uk.rs-online.com/web/p/through-hole-fixed-resistors/0135831/?searchHistory=%7B%22enabled%22%3Atrue%7D
 | 7 | 0 | 7 | Address | Package_DIP:DIP_SW-8_W7.62mm_LongPads | https://docs.rs-online.com/dee5/0900766b813ebdbf.pdf | https://uk.rs-online.com/web/p/dip-sip-switches/0342102/
 | 7 | 4 | 3 | HC-SR04 | Sensor_Distance:HC-SR04 | https://docs.rs-online.com/8bc5/A700000007388293.pdf | https://uk.rs-online.com/web/p/bbc-micro-bit-add-ons/2153181/
 | 7 | 9 | 0 | ESP32_DevKit_V4 | ESP32_DevKit_V4:esp32_devkit_v4 | https://docs.espressif.com/projects/esp-idf/en/latest/esp32/hw-reference/esp32/get-started-devkitc.html | https://www.amazon.co.uk/Dorhea-ESP32-DevKitC-Development-ESP32-WROOM-32U-Amplifier/dp/B08T5RBCXS
 | 7 | 2 | 5 | LM2675N-5 | Package_DIP:DIP-8_W7.62mm | http://www.ti.com/lit/ds/symlink/lm2675.pdf | https://uk.farnell.com/texas-instruments/lm2675n-5-0-nopb/ic-dc-dc-converter-1a/dp/3122905?st=lm2675n-5

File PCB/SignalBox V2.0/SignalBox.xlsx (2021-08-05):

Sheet: BOM
Reference | Value | Footprint | Datasheet | Source
C1 | 100uF | Capacitor_THT:CP_Radial_D5.0mm_P2.00mm | https://docs.rs-online.com/bcd8/0900766b814894c5.pdf | https://uk.rs-online.com/web/p/aluminium-capacitors/3150962/
C2 | 10nF | Capacitor_THT:C_Rect_L10.0mm_W4.0mm_P7.50mm_MKS4 | https://docs.rs-online.com/9793/0900766b814700cb.pdf | https://uk.rs-online.com/web/p/polypropylene-film-capacitors/8961512/
C3 | 68uF | Capacitor_THT:C_Radial_D4.0mm_H7.0mm_P1.50mm | https://docs.rs-online.com/f424/0900766b80becf93.pdf | https://uk.rs-online.com/web/p/aluminium-capacitors/0572312/
D2 | 1N5819RL | Diode_THT:D_DO-41_SOD81_P7.62mm_Horizontal | https://docs.rs-online.com/6961/0900766b80da3e32.pdf | https://uk.rs-online.com/web/p/schottky-diodes-rectifiers/6870754/
J1 | Power Connector | Pauls Parts:2WayScrewTerminal_2.54 | https://docs.rs-online.com/90f4/0900766b8157c7e9.pdf | https://uk.rs-online.com/web/p/pcb-terminal-blocks/7901098/
J2 | Master/Slave | Button_Switch_THT:SW_DIP_SPSTx01_Slide_6.7x4.1mm_W7.62mm_P2.54mm_LowProfile | https://docs.rs-online.com/383f/0900766b80dbe1c6.pdf | https://uk.rs-online.com/web/p/dip-sip-switches/6821058/
J3 | Buttons | Pauls Parts:4WayScrewTerminal_2.54mm | https://docs.rs-online.com/02e6/0900766b8157c7ed.pdf | https://uk.rs-online.com/web/p/pcb-terminal-blocks/7901102/
J4 | Conn_02x25_Odd_Even | Connector_IDC:IDC-Header_2x25_P2.54mm_Vertical | https://docs.rs-online.com/fea6/0900766b815867b9.pdf | https://uk.rs-online.com/web/p/pcb-headers/6257353/
J5 | Conn_02x25_Odd_Even | Connector_IDC:IDC-Header_2x25_P2.54mm_Vertical | https://docs.rs-online.com/fea6/0900766b815867b9.pdf | https://uk.rs-online.com/web/p/pcb-headers/6257353/
L1 | 47uH | Inductor_THT:L_Toroid_Vertical_L14.7mm_W8.6mm_P5.58mm_Pulse_KM-1 | https://docs.rs-online.com/24ef/0900766b81505716.pdf | https://uk.rs-online.com/web/p/leaded-inductors/1048418/
R1 | 10K | Resistor_THT:R_Axial_DIN0204_L3.6mm_D1.6mm_P5.08mm_Horizontal | https://docs.rs-online.com/76ca/0900766b8157ae01.pdf | https://uk.rs-online.com/web/p/through-hole-fixed-resistors/7077745/
R10 | 1K2 | Resistor_THT:R_Axial_DIN0204_L3.6mm_D1.6mm_P5.08mm_Horizontal | https://docs.rs-online.com/ce35/0900766b8157adf1.pdf | https://uk.rs-online.com/web/p/through-hole-fixed-resistors/7077678/
R11 | 1K2 | Resistor_THT:R_Axial_DIN0204_L3.6mm_D1.6mm_P5.08mm_Horizontal | https://docs.rs-online.com/ce35/0900766b8157adf1.pdf | https://uk.rs-online.com/web/p/through-hole-fixed-resistors/7077678/
R12 | 1K2 | Resistor_THT:R_Axial_DIN0204_L3.6mm_D1.6mm_P5.08mm_Horizontal | https://docs.rs-online.com/ce35/0900766b8157adf1.pdf | https://uk.rs-online.com/web/p/through-hole-fixed-resistors/7077678/
R13 | 1K2 | Resistor_THT:R_Axial_DIN0204_L3.6mm_D1.6mm_P5.08mm_Horizontal | https://docs.rs-online.com/ce35/0900766b8157adf1.pdf | https://uk.rs-online.com/web/p/through-hole-fixed-resistors/7077678/
R14 | 1K2 | Resistor_THT:R_Axial_DIN0204_L3.6mm_D1.6mm_P5.08mm_Horizontal | https://docs.rs-online.com/ce35/0900766b8157adf1.pdf | https://uk.rs-online.com/web/p/through-hole-fixed-resistors/7077678/
R15 | 1K2 | Resistor_THT:R_Axial_DIN0204_L3.6mm_D1.6mm_P5.08mm_Horizontal | https://docs.rs-online.com/ce35/0900766b8157adf1.pdf | https://uk.rs-online.com/web/p/through-hole-fixed-resistors/7077678/
R16 | 1K2 | Resistor_THT:R_Axial_DIN0204_L3.6mm_D1.6mm_P5.08mm_Horizontal | https://docs.rs-online.com/ce35/0900766b8157adf1.pdf | https://uk.rs-online.com/web/p/through-hole-fixed-resistors/7077678/
R17 | 1K2 | Resistor_THT:R_Axial_DIN0204_L3.6mm_D1.6mm_P5.08mm_Horizontal | https://docs.rs-online.com/ce35/0900766b8157adf1.pdf | https://uk.rs-online.com/web/p/through-hole-fixed-resistors/7077678/
R18 | 1K2 | Resistor_THT:R_Axial_DIN0204_L3.6mm_D1.6mm_P5.08mm_Horizontal | https://docs.rs-online.com/ce35/0900766b8157adf1.pdf | https://uk.rs-online.com/web/p/through-hole-fixed-resistors/7077678/
R19 | 1K2 | Resistor_THT:R_Axial_DIN0204_L3.6mm_D1.6mm_P5.08mm_Horizontal | https://docs.rs-online.com/ce35/0900766b8157adf1.pdf | https://uk.rs-online.com/web/p/through-hole-fixed-resistors/7077678/
R2 | 1K2 | Resistor_THT:R_Axial_DIN0204_L3.6mm_D1.6mm_P5.08mm_Horizontal | https://docs.rs-online.com/ce35/0900766b8157adf1.pdf | https://uk.rs-online.com/web/p/through-hole-fixed-resistors/7077678/
R20 | 1K2 | Resistor_THT:R_Axial_DIN0204_L3.6mm_D1.6mm_P5.08mm_Horizontal | https://docs.rs-online.com/ce35/0900766b8157adf1.pdf | https://uk.rs-online.com/web/p/through-hole-fixed-resistors/7077678/
R21 | 470R | Resistor_THT:R_Axial_DIN0204_L3.6mm_D1.6mm_P5.08mm_Horizontal | https://docs.rs-online.com/b9c3/0900766b8157ade8.pdf | https://uk.rs-online.com/web/p/through-hole-fixed-resistors/7077647/
R22 | 1K2 | Resistor_THT:R_Axial_DIN0204_L3.6mm_D1.6mm_P5.08mm_Horizontal | https://docs.rs-online.com/ce35/0900766b8157adf1.pdf | https://uk.rs-online.com/web/p/through-hole-fixed-resistors/7077678/
R23 | 470R | Resistor_THT:R_Axial_DIN0204_L3.6mm_D1.6mm_P5.08mm_Horizontal | https://docs.rs-online.com/b9c3/0900766b8157ade8.pdf | https://uk.rs-online.com/web/p/through-hole-fixed-resistors/7077647/
R24 | 1K2 | Resistor_THT:R_Axial_DIN0204_L3.6mm_D1.6mm_P5.08mm_Horizontal | https://docs.rs-online.com/ce35/0900766b8157adf1.pdf | https://uk.rs-online.com/web/p/through-hole-fixed-resistors/7077678/
R25 | 470R | Resistor_THT:R_Axial_DIN0204_L3.6mm_D1.6mm_P5.08mm_Horizontal | https://docs.rs-online.com/b9c3/0900766b8157ade8.pdf | https://uk.rs-online.com/web/p/through-hole-fixed-resistors/7077647/
R26 | 1K2 | Resistor_THT:R_Axial_DIN0204_L3.6mm_D1.6mm_P5.08mm_Horizontal | https://docs.rs-online.com/ce35/0900766b8157adf1.pdf | https://uk.rs-online.com/web/p/through-hole-fixed-resistors/7077678/
R27 | 470R | Resistor_THT:R_Axial_DIN0204_L3.6mm_D1.6mm_P5.08mm_Horizontal | https://docs.rs-online.com/b9c3/0900766b8157ade8.pdf | https://uk.rs-online.com/web/p/through-hole-fixed-resistors/7077647/
R28 | 1K2 | Resistor_THT:R_Axial_DIN0204_L3.6mm_D1.6mm_P5.08mm_Horizontal | https://docs.rs-online.com/ce35/0900766b8157adf1.pdf | https://uk.rs-online.com/web/p/through-hole-fixed-resistors/7077678/
R29 | 470R | Resistor_THT:R_Axial_DIN0204_L3.6mm_D1.6mm_P5.08mm_Horizontal | https://docs.rs-online.com/b9c3/0900766b8157ade8.pdf | https://uk.rs-online.com/web/p/through-hole-fixed-resistors/7077647/
R3 | 820R | Resistor_THT:R_Axial_DIN0204_L3.6mm_D1.6mm_P5.08mm_Horizontal | https://docs.rs-online.com/8878/0900766b8157adeb.pdf | https://uk.rs-online.com/web/p/through-hole-fixed-resistors/7077669/
R30 | 1K2 | Resistor_THT:R_Axial_DIN0204_L3.6mm_D1.6mm_P5.08mm_Horizontal | https://docs.rs-online.com/ce35/0900766b8157adf1.pdf | https://uk.rs-online.com/web/p/through-hole-fixed-resistors/7077678/
R31 | 470R | Resistor_THT:R_Axial_DIN0204_L3.6mm_D1.6mm_P5.08mm_Horizontal | https://docs.rs-online.com/b9c3/0900766b8157ade8.pdf | https://uk.rs-online.com/web/p/through-hole-fixed-resistors/7077647/
R32 | 1K2 | Resistor_THT:R_Axial_DIN0204_L3.6mm_D1.6mm_P5.08mm_Horizontal | https://docs.rs-online.com/ce35/0900766b8157adf1.pdf | https://uk.rs-online.com/web/p/through-hole-fixed-resistors/7077678/
R33 | 470R | Resistor_THT:R_Axial_DIN0204_L3.6mm_D1.6mm_P5.08mm_Horizontal | https://docs.rs-online.com/b9c3/0900766b8157ade8.pdf | https://uk.rs-online.com/web/p/through-hole-fixed-resistors/7077647/
R34 | 1K2 | Resistor_THT:R_Axial_DIN0204_L3.6mm_D1.6mm_P5.08mm_Horizontal | https://docs.rs-online.com/ce35/0900766b8157adf1.pdf | https://uk.rs-online.com/web/p/through-hole-fixed-resistors/7077678/
R35 | 470R | Resistor_THT:R_Axial_DIN0204_L3.6mm_D1.6mm_P5.08mm_Horizontal | https://docs.rs-online.com/b9c3/0900766b8157ade8.pdf | https://uk.rs-online.com/web/p/through-hole-fixed-resistors/7077647/
R36 | 1K2 | Resistor_THT:R_Axial_DIN0204_L3.6mm_D1.6mm_P5.08mm_Horizontal | https://docs.rs-online.com/ce35/0900766b8157adf1.pdf | https://uk.rs-online.com/web/p/through-hole-fixed-resistors/7077678/
R37 | 470R | Resistor_THT:R_Axial_DIN0204_L3.6mm_D1.6mm_P5.08mm_Horizontal | https://docs.rs-online.com/b9c3/0900766b8157ade8.pdf | https://uk.rs-online.com/web/p/through-hole-fixed-resistors/7077647/
R38 | 1K2 | Resistor_THT:R_Axial_DIN0204_L3.6mm_D1.6mm_P5.08mm_Horizontal | https://docs.rs-online.com/ce35/0900766b8157adf1.pdf | https://uk.rs-online.com/web/p/through-hole-fixed-resistors/7077678/
R39 | 470R | Resistor_THT:R_Axial_DIN0204_L3.6mm_D1.6mm_P5.08mm_Horizontal | https://docs.rs-online.com/b9c3/0900766b8157ade8.pdf | https://uk.rs-online.com/web/p/through-hole-fixed-resistors/7077647/
R4 | 1K2 | Resistor_THT:R_Axial_DIN0204_L3.6mm_D1.6mm_P5.08mm_Horizontal | https://docs.rs-online.com/ce35/0900766b8157adf1.pdf | https://uk.rs-online.com/web/p/through-hole-fixed-resistors/7077678/
R40 | 1K2 | Resistor_THT:R_Axial_DIN0204_L3.6mm_D1.6mm_P5.08mm_Horizontal | https://docs.rs-online.com/ce35/0900766b8157adf1.pdf | https://uk.rs-online.com/web/p/through-hole-fixed-resistors/7077678/
R41 | 470R | Resistor_THT:R_Axial_DIN0204_L3.6mm_D1.6mm_P5.08mm_Horizontal | https://docs.rs-online.com/b9c3/0900766b8157ade8.pdf | https://uk.rs-online.com/web/p/through-hole-fixed-resistors/7077647/
R42 | 1K2 | Resistor_THT:R_Axial_DIN0204_L3.6mm_D1.6mm_P5.08mm_Horizontal | https://docs.rs-online.com/ce35/0900766b8157adf1.pdf | https://uk.rs-online.com/web/p/through-hole-fixed-resistors/7077678/
R43 | 470R | Resistor_THT:R_Axial_DIN0204_L3.6mm_D1.6mm_P5.08mm_Horizontal | https://docs.rs-online.com/b9c3/0900766b8157ade8.pdf | https://uk.rs-online.com/web/p/through-hole-fixed-resistors/7077647/
R44 | 1K2 | Resistor_THT:R_Axial_DIN0204_L3.6mm_D1.6mm_P5.08mm_Horizontal | https://docs.rs-online.com/ce35/0900766b8157adf1.pdf | https://uk.rs-online.com/web/p/through-hole-fixed-resistors/7077678/
R45 | 470R | Resistor_THT:R_Axial_DIN0204_L3.6mm_D1.6mm_P5.08mm_Horizontal | https://docs.rs-online.com/b9c3/0900766b8157ade8.pdf | https://uk.rs-online.com/web/p/through-hole-fixed-resistors/7077647/
R46 | 1K2 | Resistor_THT:R_Axial_DIN0204_L3.6mm_D1.6mm_P5.08mm_Horizontal | https://docs.rs-online.com/ce35/0900766b8157adf1.pdf | https://uk.rs-online.com/web/p/through-hole-fixed-resistors/7077678/
R47 | 470R | Resistor_THT:R_Axial_DIN0204_L3.6mm_D1.6mm_P5.08mm_Horizontal | https://docs.rs-online.com/b9c3/0900766b8157ade8.pdf | https://uk.rs-online.com/web/p/through-hole-fixed-resistors/7077647/
R48 | 1K2 | Resistor_THT:R_Axial_DIN0204_L3.6mm_D1.6mm_P5.08mm_Horizontal | https://docs.rs-online.com/ce35/0900766b8157adf1.pdf | https://uk.rs-online.com/web/p/through-hole-fixed-resistors/7077678/
R49 | 470R | Resistor_THT:R_Axial_DIN0204_L3.6mm_D1.6mm_P5.08mm_Horizontal | https://docs.rs-online.com/b9c3/0900766b8157ade8.pdf | https://uk.rs-online.com/web/p/through-hole-fixed-resistors/7077647/
R5 | 1K2 | Resistor_THT:R_Axial_DIN0204_L3.6mm_D1.6mm_P5.08mm_Horizontal | https://docs.rs-online.com/ce35/0900766b8157adf1.pdf | https://uk.rs-online.com/web/p/through-hole-fixed-resistors/7077678/
R50 | 1K2 | Resistor_THT:R_Axial_DIN0204_L3.6mm_D1.6mm_P5.08mm_Horizontal | https://docs.rs-online.com/ce35/0900766b8157adf1.pdf | https://uk.rs-online.com/web/p/through-hole-fixed-resistors/7077678/
R51 | 1K2 | Resistor_THT:R_Axial_DIN0204_L3.6mm_D1.6mm_P5.08mm_Horizontal | https://docs.rs-online.com/ce35/0900766b8157adf1.pdf | https://uk.rs-online.com/web/p/through-hole-fixed-resistors/7077678/
R52 | 470R | Resistor_THT:R_Axial_DIN0204_L3.6mm_D1.6mm_P5.08mm_Horizontal | https://docs.rs-online.com/b9c3/0900766b8157ade8.pdf | https://uk.rs-online.com/web/p/through-hole-fixed-resistors/7077647/
R53 | 330R | Resistor_THT:R_Axial_DIN0204_L3.6mm_D1.6mm_P5.08mm_Horizontal | https://docs.rs-online.com/8434/0900766b8157ade3.pdf | https://uk.rs-online.com/web/p/through-hole-fixed-resistors/7077622/
R6 | 470R | Resistor_THT:R_Axial_DIN0204_L3.6mm_D1.6mm_P5.08mm_Horizontal | https://docs.rs-online.com/b9c3/0900766b8157ade8.pdf | https://uk.rs-online.com/web/p/through-hole-fixed-resistors/7077647/
R7 | 470R | Resistor_THT:R_Axial_DIN0204_L3.6mm_D1.6mm_P5.08mm_Horizontal | https://docs.rs-online.com/b9c3/0900766b8157ade8.pdf | https://uk.rs-online.com/web/p/through-hole-fixed-resistors/7077647/
R8 | 1K2 | Resistor_THT:R_Axial_DIN0204_L3.6mm_D1.6mm_P5.08mm_Horizontal | https://docs.rs-online.com/ce35/0900766b8157adf1.pdf | https://uk.rs-online.com/web/p/through-hole-fixed-resistors/7077678/
R9 | 1K2 | Resistor_THT:R_Axial_DIN0204_L3.6mm_D1.6mm_P5.08mm_Horizontal | https://docs.rs-online.com/ce35/0900766b8157adf1.pdf | https://uk.rs-online.com/web/p/through-hole-fixed-resistors/7077678/
U1 | ESP32_DevKit_V4 | ESP32_DevKit_V4:esp32_devkit_v4 | https://docs.espressif.com/projects/esp-idf/en/latest/esp32/hw-reference/esp32/get-started-devkitc.html | https://www.amazon.co.uk/Dorhea-ESP32-DevKitC-Development-ESP32-WROOM-32U-Amplifier/dp/B08T5RBCXS
U2 | MCP23017_SP | Package_DIP:DIP-28_W7.62mm | https://docs.rs-online.com/3aed/0900766b8137eed4.pdf | https://uk.rs-online.com/web/p/io-expanders/0403806/
U3 | MCP23017_SP | Package_DIP:DIP-28_W7.62mm | https://docs.rs-online.com/3aed/0900766b8137eed4.pdf | https://uk.rs-online.com/web/p/io-expanders/0403806/
U4 | LM2675N-5 | Package_DIP:DIP-8_W7.62mm | http://www.ti.com/lit/ds/symlink/lm2675.pdf | https://uk.farnell.com/texas-instruments/lm2675n-5-0-nopb/ic-dc-dc-converter-1a/dp/3122905?st=lm2675n-5
Non board parts
1 | 2.4GHz Antenna |  |  | https://www.ebay.co.uk/itm/202185734795?chn=ps&mkevt=1&mkcid=28&var=502163080733
17 | Green LED | 3.2 V Green LED 5mm Through Hole | https://docs.rs-online.com/5a16/0900766b8162d8a7.pdf | https://uk.rs-online.com/web/p/leds/1682428/
16 | Red LED | 1.9 V Red LED 5mm Through Hole | https://docs.rs-online.com/436b/0900766b8162d8d6.pdf | https://uk.rs-online.com/web/p/leds/1682471/
17 | Yellow LED | 1.9 V Yellow LED 5mm Through Hole | https://docs.rs-online.com/f8c6/0900766b8162d8d7.pdf | https://uk.rs-online.com/web/p/leds/1682378/
2 | Cable connector | RS PRO 50-Way IDC Connector Socket for Cable Mount, 2-Row | https://docs.rs-online.com/337d/0900766b815867b0.pdf | https://uk.rs-online.com/web/p/idc-connectors/6257325/
1m | Ribbon cable | RS PRO 50 Way Unscreened Flat Ribbon Cable, 63.5 mm Width | https://docs.rs-online.com/65f0/0900766b8151cc7c.pdf | https://uk.rs-online.com/web/p/flat-ribbon-cable/2899981/
50 | LED holder | Bivar C-175, C Series LED Holder for 5mm (T-1 3/4) Flanged LED | https://docs.rs-online.com/7ad3/0900766b814a658c.pdf | https://uk.rs-online.com/web/p/led-holders/9067396/
2.5m | Heat shrink tubing for LED cable termination. 25mm lengths | HellermannTyton Adhesive Lined Heat Shrink Tubing, Black 3.2mm Sleeve Dia. x 1.2m Length 3:1 Ratio, TA32 Series | https://docs.rs-online.com/bcff/0900766b8149298d.pdf | https://uk.rs-online.com/web/p/heat-shrink-cold-shrink-sleeves/8326965/

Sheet: Grouped
Reference | Quantity | Value | Footprint | Datasheet | Source
C1 | 1 | 100uF | Capacitor_THT:CP_Radial_D5.0mm_P2.00mm | https://docs.rs-online.com/bcd8/0900766b814894c5.pdf | https://uk.rs-online.com/web/p/aluminium-capacitors/3150962/
C2 | 1 | 10nF | Capacitor_THT:C_Rect_L10.0mm_W4.0mm_P7.50mm_MKS4 | https://docs.rs-online.com/9793/0900766b814700cb.pdf | https://uk.rs-online.com/web/p/polypropylene-film-capacitors/8961512/
C3 | 1 | 68uF | Capacitor_THT:C_Radial_D4.0mm_H7.0mm_P1.50mm | https://docs.rs-online.com/f424/0900766b80becf93.pdf | https://uk.rs-online.com/web/p/aluminium-capacitors/0572312/
D2 | 1 | 1N5819RL | Diode_THT:D_DO-41_SOD81_P7.62mm_Horizontal | https://docs.rs-online.com/6961/0900766b80da3e32.pdf | https://uk.rs-online.com/web/p/schottky-diodes-rectifiers/6870754/
J1 | 1 | Power Connector | Pauls Parts:2WayScrewTerminal_2.54 | https://docs.rs-online.com/90f4/0900766b8157c7e9.pdf | https://uk.rs-online.com/web/p/pcb-terminal-blocks/7901098/
J2 | 1 | Master/Slave | Button_Switch_THT:SW_DIP_SPSTx01_Slide_6.7x4.1mm_W7.62mm_P2.54mm_LowProfile | https://docs.rs-online.com/383f/0900766b80dbe1c6.pdf | https://uk.rs-online.com/web/p/dip-sip-switches/6821058/
J3 | 1 | Buttons | Pauls Parts:4WayScrewTerminal_2.54mm | https://docs.rs-online.com/02e6/0900766b8157c7ed.pdf | https://uk.rs-online.com/web/p/pcb-terminal-blocks/7901102/
J4 J5 | 2 | Conn_02x25_Odd_Even | Connector_IDC:IDC-Header_2x25_P2.54mm_Vertical | https://docs.rs-online.com/fea6/0900766b815867b9.pdf | https://uk.rs-online.com/web/p/pcb-headers/6257353/
L1 | 1 | 47uH | Inductor_THT:L_Toroid_Vertical_L14.7mm_W8.6mm_P5.58mm_Pulse_KM-1 | https://docs.rs-online.com/24ef/0900766b81505716.pdf | https://uk.rs-online.com/web/p/leaded-inductors/1048418/
R1 | 1 | 10K | Resistor_THT:R_Axial_DIN0204_L3.6mm_D1.6mm_P5.08mm_Horizontal | https://docs.rs-online.com/76ca/0900766b8157ae01.pdf | https://uk.rs-online.com/web/p/through-hole-fixed-resistors/7077745/
R3 | 1 | 820R | Resistor_THT:R_Axial_DIN0204_L3.6mm_D1.6mm_P5.08mm_Horizontal | https://docs.rs-online.com/8878/0900766b8157adeb.pdf | https://uk.rs-online.com/web/p/through-hole-fixed-resistors/7077669/
R2 R4 R5 R8 R9 R10 R11 R12 R13 R14 R15 R16 R17 R18 R19 R20 R22 R24 R26 R28 R30 R32 R34 R36 R38 R40 R42 R44 R46 R48 R50 R51 | 32 | 1K2 | Resistor_THT:R_Axial_DIN0204_L3.6mm_D1.6mm_P5.08mm_Horizontal | https://docs.rs-online.com/ce35/0900766b8157adf1.pdf | https://uk.rs-online.com/web/p/through-hole-fixed-resistors/7077678/
R53 | 1 | 330R | Resistor_THT:R_Axial_DIN0204_L3.6mm_D1.6mm_P5.08mm_Horizontal | https://docs.rs-online.com/8434/0900766b8157ade3.pdf | https://uk.rs-online.com/web/p/through-hole-fixed-resistors/7077622/
R6 R7 R21 R23 R25 R27 R29 R31 R33 R35 R37 R39 R41 R43 R45 R47 R49 R52 | 18 | 470R | Resistor_THT:R_Axial_DIN0204_L3.6mm_D1.6mm_P5.08mm_Horizontal | https://docs.rs-online.com/b9c3/0900766b8157ade8.pdf | https://uk.rs-online.com/web/p/through-hole-fixed-resistors/7077647/
U1 | 1 | ESP32_DevKit_V4 | ESP32_DevKit_V4:esp32_devkit_v4 | https://docs.espressif.com/projects/esp-idf/en/latest/esp32/hw-reference/esp32/get-started-devkitc.html | https://www.amazon.co.uk/Dorhea-ESP32-DevKitC-Development-ESP32-WROOM-32U-Amplifier/dp/B08T5RBCXS
U2 U3 | 2 | MCP23017_SP | Package_DIP:DIP-28_W7.62mm | https://docs.rs-online.com/3aed/0900766b8137eed4.pdf | https://uk.rs-online.com/web/p/io-expanders/0403806/
U4 | 1 | LM2675N-5 | Package_DIP:DIP-8_W7.62mm | http://www.ti.com/lit/ds/symlink/lm2675.pdf | https://uk.farnell.com/texas-instruments/lm2675n-5-0-nopb/ic-dc-dc-converter-1a/dp/3122905?st=lm2675n-5
 | 1 | 2.4GHz Antenna |  |  | https://www.ebay.co.uk/itm/202185734795?chn=ps&mkevt=1&mkcid=28&var=502163080733
 | 17 | Green LED | 3.2 V Green LED 5mm Through Hole | https://docs.rs-online.com/5a16/0900766b8162d8a7.pdf | https://uk.rs-online.com/web/p/leds/1682428/
 | 16 | Red LED | 1.9 V Red LED 5mm Through Hole | https://docs.rs-online.com/436b/0900766b8162d8d6.pdf | https://uk.rs-online.com/web/p/leds/1682471/
 | 17 | Yellow LED | 1.9 V Yellow LED 5mm Through Hole | https://docs.rs-online.com/f8c6/0900766b8162d8d7.pdf | https://uk.rs-online.com/web/p/leds/1682378/
 | 2 | Cable connector | RS PRO 50-Way IDC Connector Socket for Cable Mount, 2-Row | https://docs.rs-online.com/337d/0900766b815867b0.pdf | https://uk.rs-online.com/web/p/idc-connectors/6257325/
 | 1 | Ribbon cable (meters) | RS PRO 50 Way Unscreened Flat Ribbon Cable, 63.5 mm Width | https://docs.rs-online.com/65f0/0900766b8151cc7c.pdf | https://uk.rs-online.com/web/p/flat-ribbon-cable/2899981/
 | 50 | LED holder | Bivar C-175, C Series LED Holder for 5mm (T-1 3/4) Flanged LED | https://docs.rs-online.com/7ad3/0900766b814a658c.pdf | https://uk.rs-online.com/web/p/led-holders/9067396/
 | 2.5 | Heat shrink tubing for LED cable termination. 25mm lengths (meters) | HellermannTyton Adhesive Lined Heat Shrink Tubing, Black 3.2mm Sleeve Dia. x 1.2m Length 3:1 Ratio, TA32 Series | https://docs.rs-online.com/bcff/0900766b8149298d.pdf | https://uk.rs-online.com/web/p/heat-shrink-cold-shrink-sleeves/8326965/
Number of signal boards | 3
 | Quantity | Value | Footprint | Datasheet
 | 3 | 100uF | Capacitor_THT:CP_Radial_D5.0mm_P2.00mm | https://docs.rs-online.com/bcd8/0900766b814894c5.pdf | https://uk.rs-online.com/web/p/aluminium-capacitors/3150962/
 | 3 | 10nF | Capacitor_THT:C_Rect_L10.0mm_W4.0mm_P7.50mm_MKS4 | https://docs.rs-online.com/9793/0900766b814700cb.pdf | https://uk.rs-online.com/web/p/polypropylene-film-capacitors/8961512/
 | 3 | 68uF | Capacitor_THT:C_Radial_D4.0mm_H7.0mm_P1.50mm | https://docs.rs-online.com/f424/0900766b80becf93.pdf | https://uk.rs-online.com/web/p/aluminium-capacitors/0572312/
 | 3 | 1N5819RL | Diode_THT:D_DO-41_SOD81_P7.62mm_Horizontal | https://docs.rs-online.com/6961/0900766b80da3e32.pdf | https://uk.rs-online.com/web/p/schottky-diodes-rectifiers/6870754/
 | 3 | Power Connector | Pauls Parts:2WayScrewTerminal_2.54 | https://docs.rs-online.com/90f4/0900766b8157c7e9.pdf | https://uk.rs-online.com/web/p/pcb-terminal-blocks/7901098/
 | 3 | Master/Slave | Button_Switch_THT:SW_DIP_SPSTx01_Slide_6.7x4.1mm_W7.62mm_P2.54mm_LowProfile | https://docs.rs-online.com/383f/0900766b80dbe1c6.pdf | https://uk.rs-online.com/web/p/dip-sip-switches/6821058/
 | 3 | Buttons | Pauls Parts:4WayScrewTerminal_2.54mm | https://docs.rs-online.com/02e6/0900766b8157c7ed.pdf | https://uk.rs-online.com/web/p/pcb-terminal-blocks/7901102/
 | 6 | Conn_02x25_Odd_Even | Connector_IDC:IDC-Header_2x25_P2.54mm_Vertical | https://docs.rs-online.com/fea6/0900766b815867b9.pdf | https://uk.rs-online.com/web/p/pcb-headers/6257353/
 | 3 | 47uH | Inductor_THT:L_Toroid_Vertical_L14.7mm_W8.6mm_P5.58mm_Pulse_KM-1 | https://docs.rs-online.com/24ef/0900766b81505716.pdf | https://uk.rs-online.com/web/p/leaded-inductors/1048418/
 | 3 | 10K | Resistor_THT:R_Axial_DIN0204_L3.6mm_D1.6mm_P5.08mm_Horizontal | https://docs.rs-online.com/76ca/0900766b8157ae01.pdf | https://uk.rs-online.com/web/p/through-hole-fixed-resistors/7077745/
 | 3 | 820R | Resistor_THT:R_Axial_DIN0204_L3.6mm_D1.6mm_P5.08mm_Horizontal | https://docs.rs-online.com/8878/0900766b8157adeb.pdf | https://uk.rs-online.com/web/p/through-hole-fixed-resistors/7077669/
 | 96 | 1K2 | Resistor_THT:R_Axial_DIN0204_L3.6mm_D1.6mm_P5.08mm_Horizontal | https://docs.rs-online.com/ce35/0900766b8157adf1.pdf | https://uk.rs-online.com/web/p/through-hole-fixed-resistors/7077678/
 | 3 | 330R | Resistor_THT:R_Axial_DIN0204_L3.6mm_D1.6mm_P5.08mm_Horizontal | https://docs.rs-online.com/8434/0900766b8157ade3.pdf | https://uk.rs-online.com/web/p/through-hole-fixed-resistors/7077622/
 | 54 | 470R | Resistor_THT:R_Axial_DIN0204_L3.6mm_D1.6mm_P5.08mm_Horizontal | https://docs.rs-online.com/b9c3/0900766b8157ade8.pdf | https://uk.rs-online.com/web/p/through-hole-fixed-resistors/7077647/
 | 3 | ESP32_DevKit_V4 | ESP32_DevKit_V4:esp32_devkit_v4 | https://docs.espressif.com/projects/esp-idf/en/latest/esp32/hw-reference/esp32/get-started-devkitc.html | https://www.amazon.co.uk/Dorhea-ESP32-DevKitC-Development-ESP32-WROOM-32U-Amplifier/dp/B08T5RBCXS
 | 6 | MCP23017_SP | Package_DIP:DIP-28_W7.62mm | https://docs.rs-online.com/3aed/0900766b8137eed4.pdf | https://uk.rs-online.com/web/p/io-expanders/0403806/
 | 3 | LM2675N-5 | Package_DIP:DIP-8_W7.62mm | http://www.ti.com/lit/ds/symlink/lm2675.pdf | https://uk.farnell.com/texas-instruments/lm2675n-5-0-nopb/ic-dc-dc-converter-1a/dp/3122905?st=lm2675n-5
 | 0 | 0 | 0 | 0 | 0
 | 3 | 2.4GHz Antenna | 0 | 0 | https://www.ebay.co.uk/itm/202185734795?chn=ps&mkevt=1&mkcid=28&var=502163080733
 | 51 | Green LED | 3.2 V Green LED 5mm Through Hole | https://docs.rs-online.com/5a16/0900766b8162d8a7.pdf | https://uk.rs-online.com/web/p/leds/1682428/
 | 48 | Red LED | 1.9 V Red LED 5mm Through Hole | https://docs.rs-online.com/436b/0900766b8162d8d6.pdf | https://uk.rs-online.com/web/p/leds/1682471/
 | 51 | Yellow LED | 1.9 V Yellow LED 5mm Through Hole | https://docs.rs-online.com/f8c6/0900766b8162d8d7.pdf | https://uk.rs-online.com/web/p/leds/1682378/
 | 6 | Cable connector | RS PRO 50-Way IDC Connector Socket for Cable Mount, 2-Row | https://docs.rs-online.com/337d/0900766b815867b0.pdf | https://uk.rs-online.com/web/p/idc-connectors/6257325/
 | 3 | Ribbon cable (meters) | RS PRO 50 Way Unscreened Flat Ribbon Cable, 63.5 mm Width | https://docs.rs-online.com/65f0/0900766b8151cc7c.pdf | https://uk.rs-online.com/web/p/flat-ribbon-cable/2899981/
 | 150 | LED holder | Bivar C-175, C Series LED Holder for 5mm (T-1 3/4) Flanged LED | https://docs.rs-online.com/7ad3/0900766b814a658c.pdf | https://uk.rs-online.com/web/p/led-holders/9067396/
 | 7.5 | Heat shrink tubing for LED cable termination. 25mm lengths (meters) | HellermannTyton Adhesive Lined Heat Shrink Tubing, Black 3.2mm Sleeve Dia. x 1.2m Length 3:1 Ratio, TA32 Series | https://docs.rs-online.com/bcff/0900766b8149298d.pdf | https://uk.rs-online.com/web/p/heat-shrink-cold-shrink-sleeves/8326965/

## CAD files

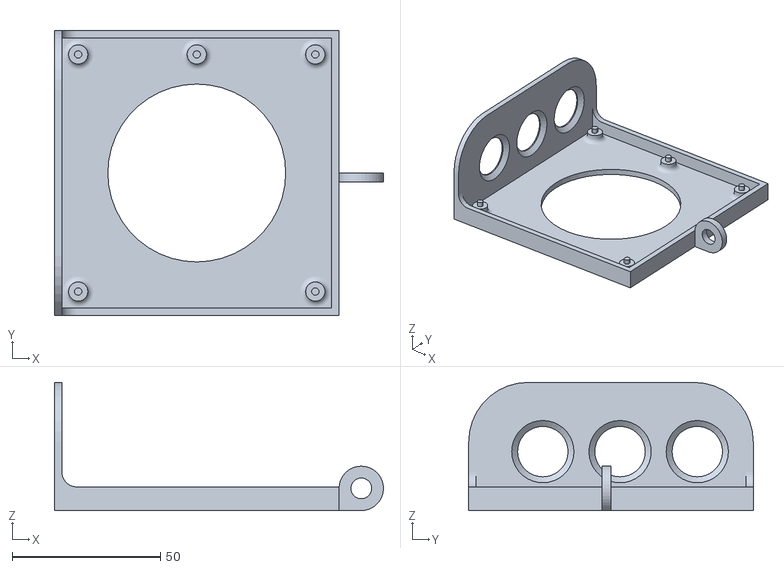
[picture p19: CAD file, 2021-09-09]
3D parts/test plate 2.stl
111.0 x 96.0 x 43.2

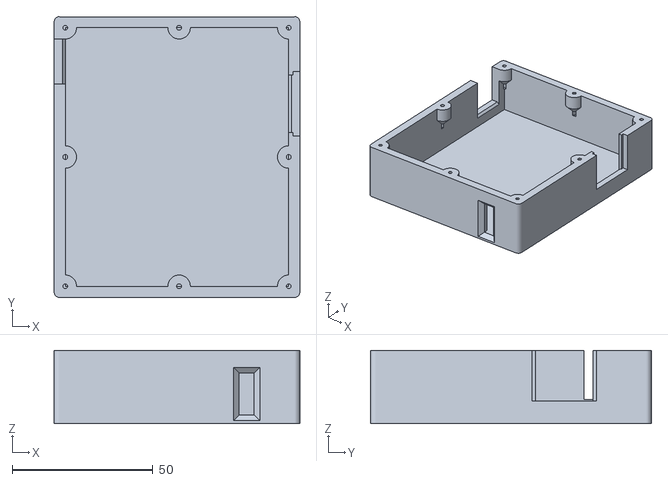
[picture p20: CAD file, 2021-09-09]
3D parts/WiFi Box.stl
87.5 x 100.0 x 26.0

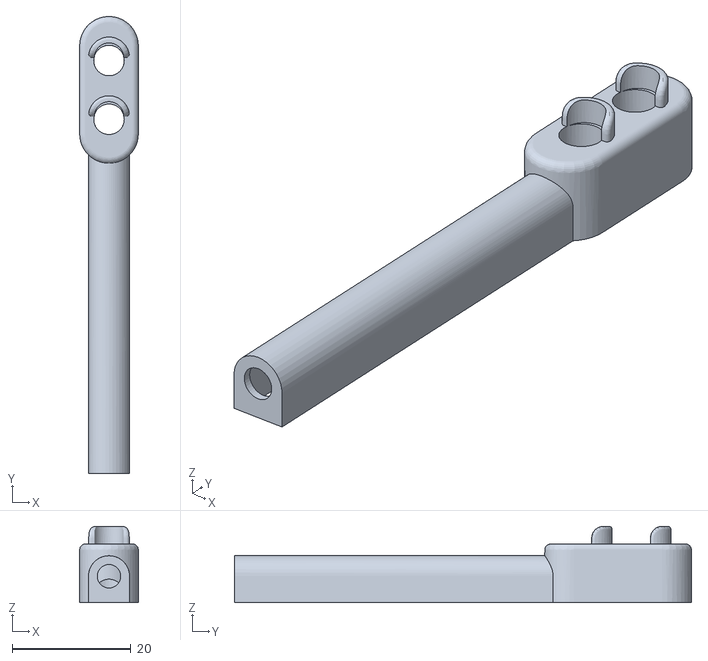
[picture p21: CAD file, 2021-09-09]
3D parts/signal.stl
9.90 x 77.1 x 12.9

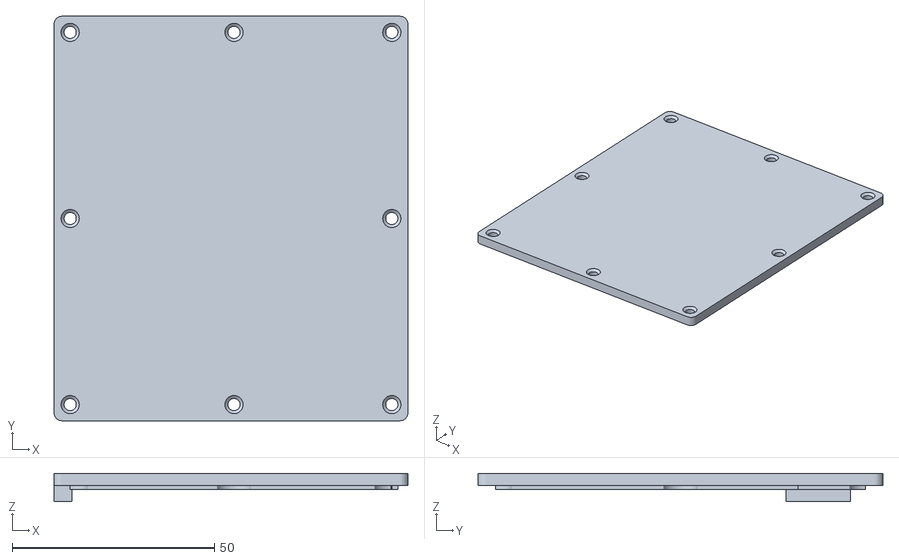
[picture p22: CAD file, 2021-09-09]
3D parts/WiFi Box Lid.stl
87.5 x 100.0 x 7.02

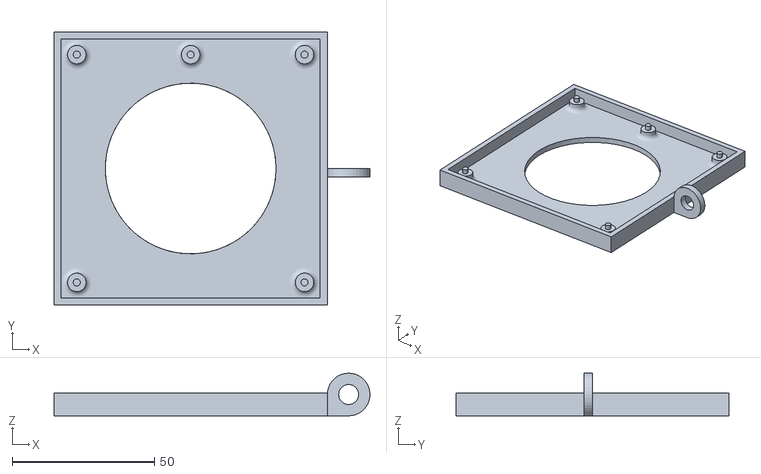
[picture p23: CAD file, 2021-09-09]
3D parts/test plate.stl
111.0 x 96.0 x 15.0

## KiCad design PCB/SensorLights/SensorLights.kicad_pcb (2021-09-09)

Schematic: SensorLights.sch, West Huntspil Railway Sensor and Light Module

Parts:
C1: 68uF; C_Radial_D4.0mm_H7.0mm_P1.50mm
D1: Yellow; LED_D5.0mm
D2: Green; LED_D5.0mm
D3: Red; LED_D5.0mm
D4: DSSK50-01A; TO-220-3_Vertical
J1: Signal Power; 2WayTerminalStrip_5mm
J2: Board Power; 2WayScrewTerminal_2.54
J3: Green Signal; 2WayTerminalStrip_5mm
J4: Red Signal; 2WayTerminalStrip_5mm
J5: Manual Stop; 2WayScrewTerminal_2.54
JP1: Jumper; PinHeader_1x02_P2.54mm_Vertical
JP2: Local Stop; PinHeader_1x02_P2.54mm_Vertical
JP3: Local Sense; PinHeader_1x02_P2.54mm_Vertical
JP4: Local WiFi; PinHeader_1x02_P2.54mm_Vertical
Q1, Q2: RFP50N06LE; TO-220-3_Vertical
R1, R2, R3, R4, R6, R9, R11, R12, R13: 10K; R_Axial_DIN0204_L3.6mm_D1.6mm_P5.08mm_Horizontal
R5, R8: 1K2; R_Axial_DIN0204_L3.6mm_D1.6mm_P5.08mm_Horizontal
R7, R10: 470R; R_Axial_DIN0204_L3.6mm_D1.6mm_P5.08mm_Horizontal
RV1, RV2: 10K; Potentiometer_TT_M64W
SW1: Address; DIP_SW-8_W7.62mm_LongPads
U1: HC-SR04
U2: ESP32_DevKit_V4; esp32_devkit_v4

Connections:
+5V: R1.1, R2.1, R3.1, R4.1, R5.1, R7.1, R8.1, R10.1, R11.1, R12.1, R13.1, RV1.1, RV2.1, U1.4 (Vcc), U2.19 (VIN); also elsewhere on the board
/5V Supply/6V-24V: J2.2, JP1.2; also elsewhere on the board
GND: C1.2, J1.1, J2.1, J5.1, JP2.2, JP3.2, JP4.2, Q1.3 (S), Q2.3 (S), R6.2, R9.2, RV1.3, RV2.3, SW1.1, SW1.2, SW1.3, SW1.4, U1.1 (Gnd), U2.14 (GND), U2.32 (GND), U2.38 (GND); also elsewhere on the board
unnamed: D1.1 (K), U2.27 (IO16)
unnamed: D1.2 (A), R5.2
unnamed: D2.1 (K), U2.28 (IO17)
unnamed: D2.2 (A), R7.2
unnamed: D3.1 (K), U2.30 (IO18)
unnamed: D3.2 (A), R8.2
unnamed: D4.1 (A), J4.1, Q2.2 (D)
unnamed: D4.3 (A), J3.1, Q1.2 (D)
unnamed: JP2.1, R11.2, U2.12 (IO14)
unnamed: JP3.1, R12.2, U2.15 (IO13)
unnamed: Q1.1 (G), R6.1, U2.26 (IO4)
unnamed: Q2.1 (G), R9.1, U2.29 (IO5)
unnamed: R1.2, SW1.8, U2.7 (IO32)
unnamed: R2.2, SW1.7, U2.8 (IO33)
unnamed: R3.2, SW1.6, U2.5 (IO34)
unnamed: R4.2, SW1.5, U2.6 (IO35)
unnamed: RV1.2, U2.3 (IO36/SVP)
unnamed: RV2.2, U2.4 (IO39/SVN)
unnamed: U1.2 (Echo), U2.11 (IO27)
unnamed: U1.3 (Trig), U2.10 (IO26)
SignalPower: D4.2 (K), J1.2, J3.2, J4.2, JP1.1
Stop: C1.1, J5.2, R10.2, U2.23 (IO15)
lWiFi: JP4.1, R13.2, U2.9 (IO25)

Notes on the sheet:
6-60V
6-24V
Common Power Jumper
Start
Span

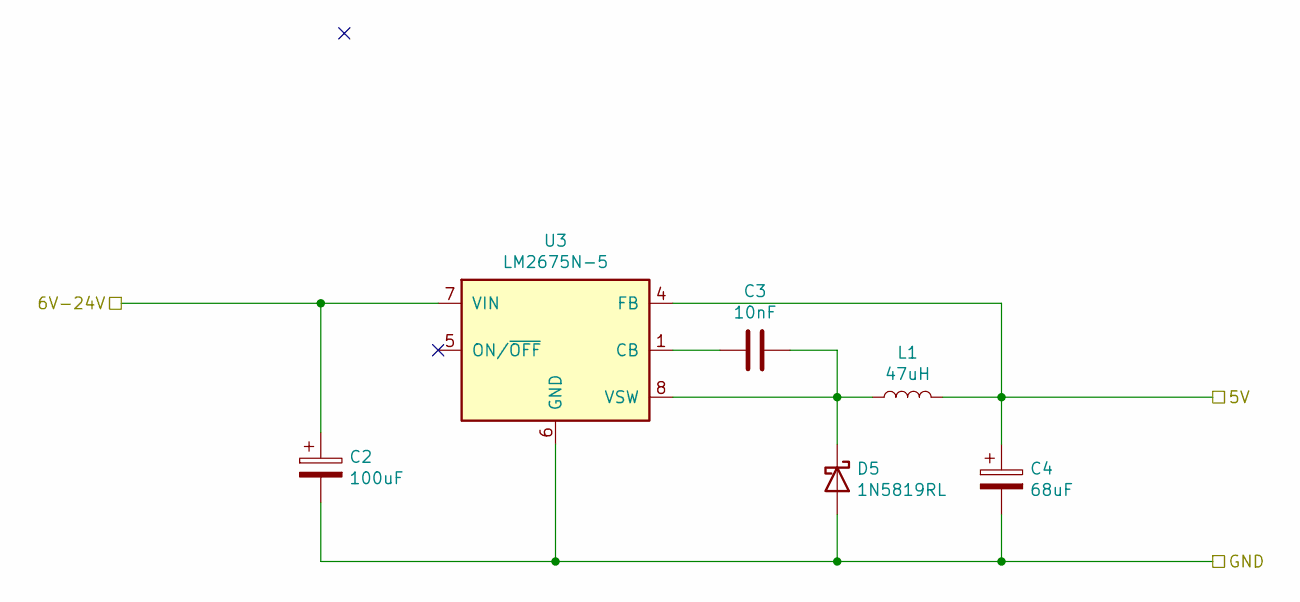
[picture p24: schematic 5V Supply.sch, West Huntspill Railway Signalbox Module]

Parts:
C2: 100uF; CP_Radial_D5.0mm_P2.00mm
C3: 10nF; C_Rect_L10.0mm_W4.0mm_P7.50mm_MKS4
C4: 68uF; C_Radial_D4.0mm_H7.0mm_P1.50mm
D5: 1N5819RL; D_DO-41_SOD81_P7.62mm_Horizontal
L1: 47uH; L_Toroid_Vertical_L14.7mm_W8.6mm_P5.58mm_Pulse_KM-1
U3: LM2675N-5; DIP-8_W7.62mm

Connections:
+5V: C4.1, L1.2, U3.4 (FB); also elsewhere on the board
/5V Supply/6V-24V: C2.1, U3.7 (VIN); also elsewhere on the board
GND: C2.2, C4.2, D5.2 (A), U3.6 (GND); also elsewhere on the board
unnamed: C3.1, D5.1 (K), L1.1, U3.8 (VSW)
unnamed: C3.2, U3.1 (CB)

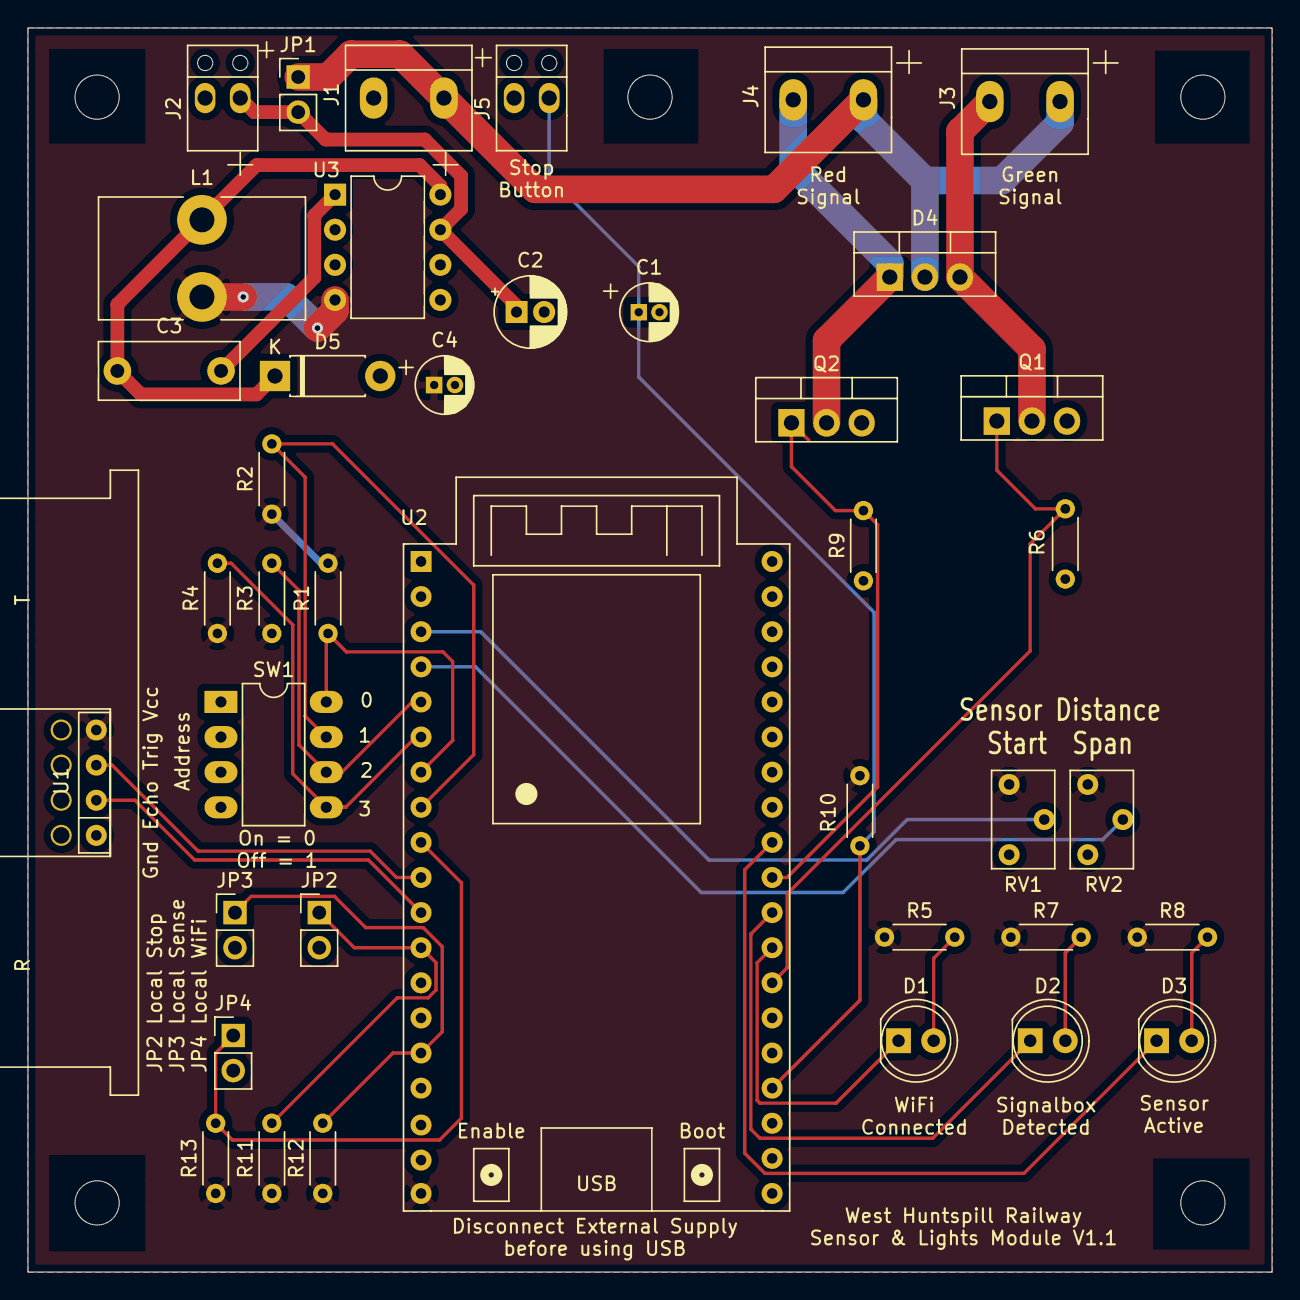
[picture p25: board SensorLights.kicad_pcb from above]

Board: 2 copper layers, 90.0 x 90.0 mm, 40 parts (0 on the bottom side), 28 nets.

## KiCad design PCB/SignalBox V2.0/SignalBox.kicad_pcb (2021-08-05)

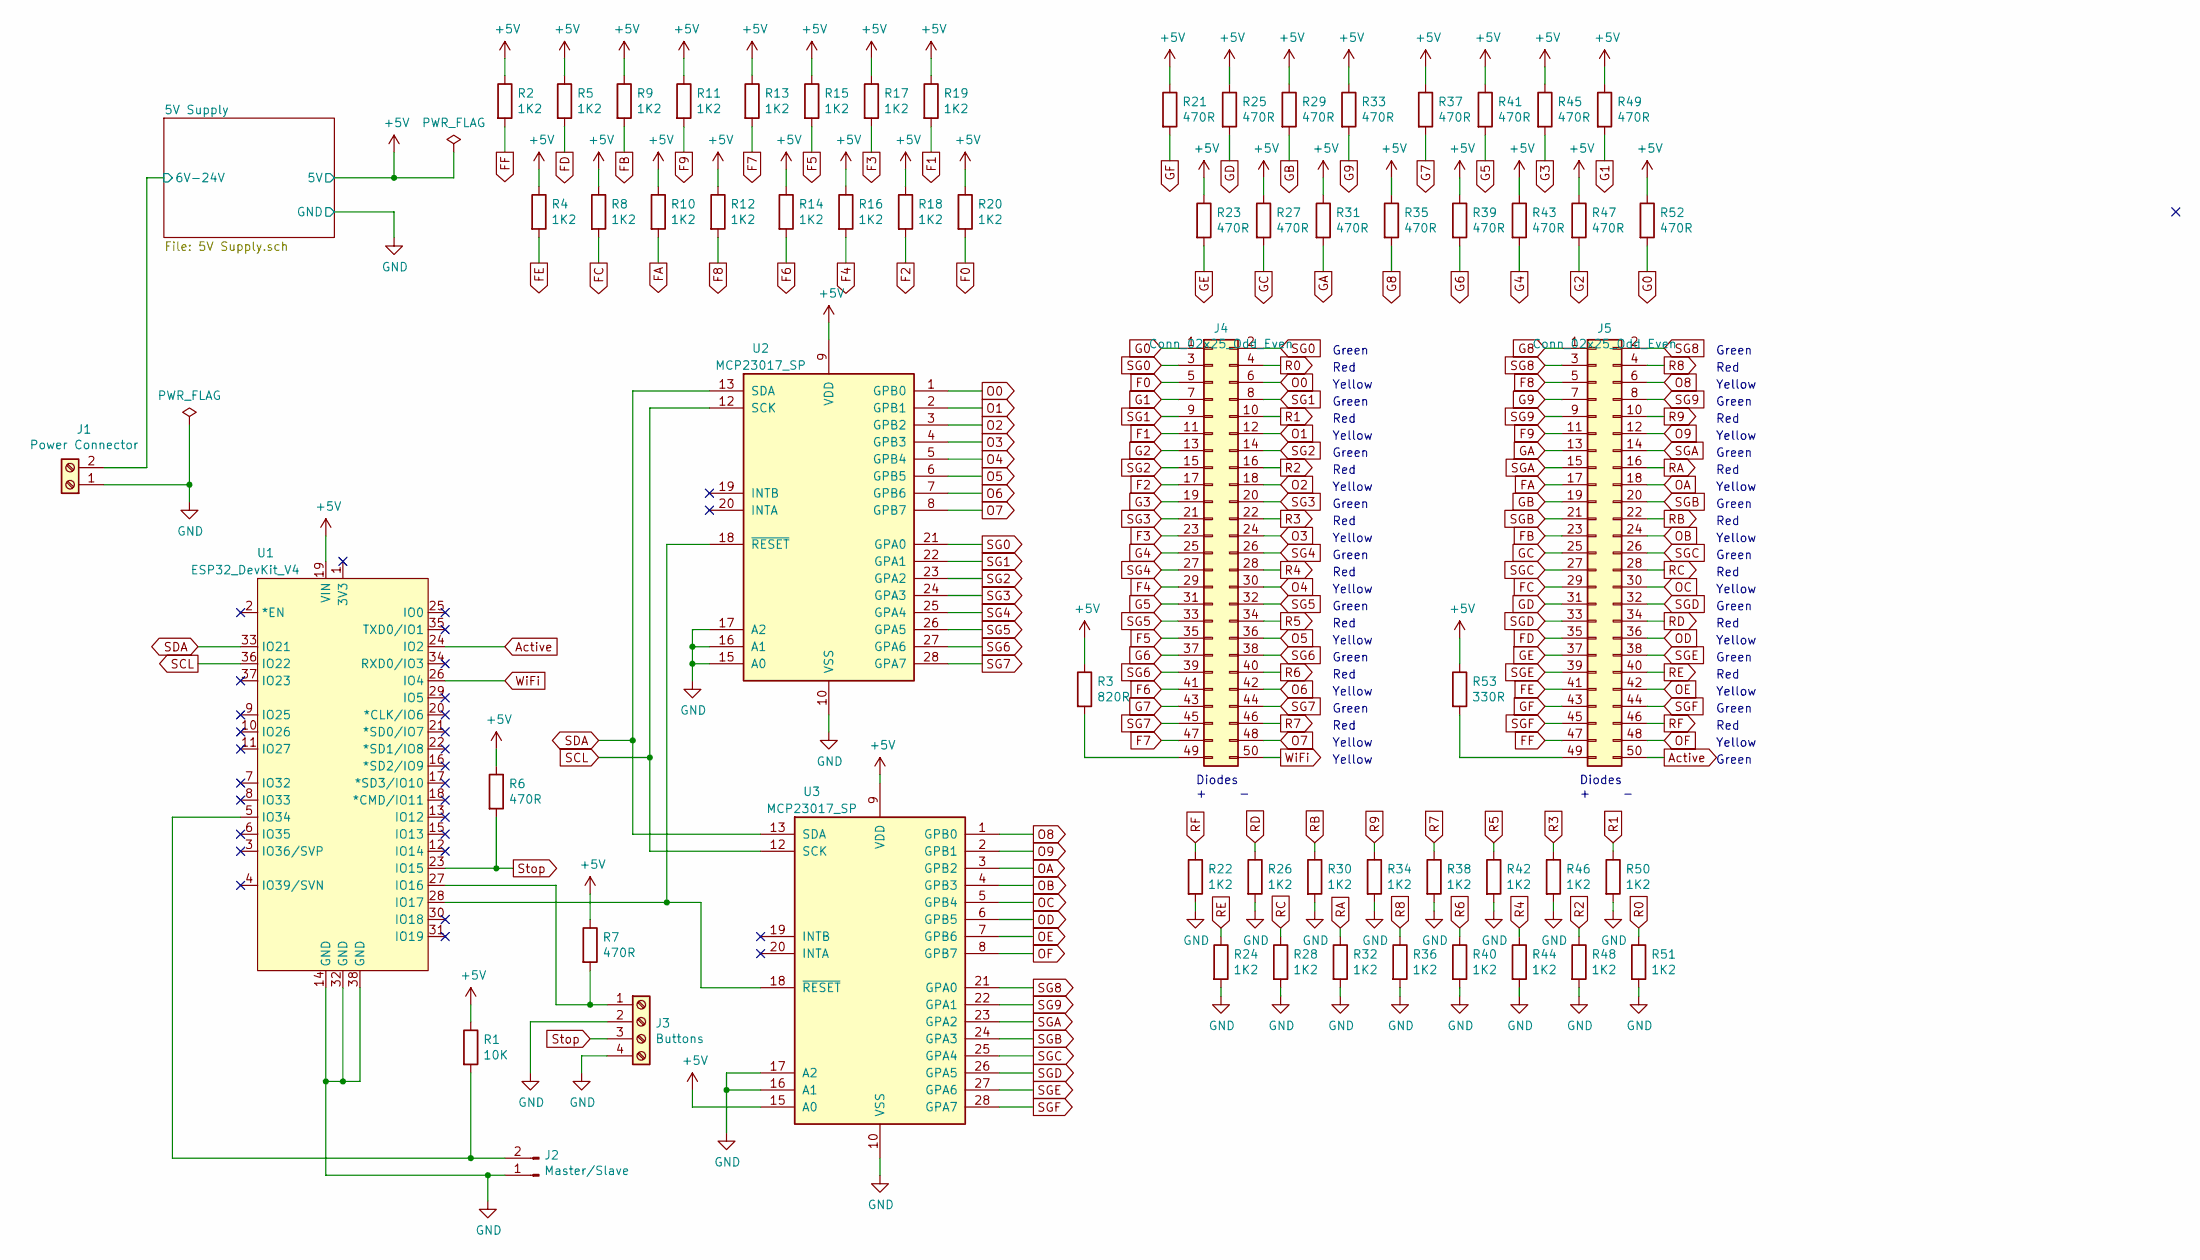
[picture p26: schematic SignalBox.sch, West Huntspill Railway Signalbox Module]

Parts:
J1: Power Connector; 2WayScrewTerminal_2.54
J2: Master/Slave; SW_DIP_SPSTx01_Slide_6.7x4.1mm_W7.62mm_P2.54mm_LowProfile
J3: Buttons; 4WayScrewTerminal_2.54mm
J4, J5: Conn_02x25_Odd_Even; IDC-Header_2x25_P2.54mm_Vertical
R1: 10K; R_Axial_DIN0204_L3.6mm_D1.6mm_P5.08mm_Horizontal
R2, R4, R5, R8, R9, R10, R11, R12, R13, R14, R15, R16, R17, R18, R19, R20, R22, R24, R26, R28, R30, R32, R34, R36, R38, R40, R42, R44, R46, R48, R50, R51: 1K2; R_Axial_DIN0204_L3.6mm_D1.6mm_P5.08mm_Horizontal
R3: 820R; R_Axial_DIN0204_L3.6mm_D1.6mm_P5.08mm_Horizontal
R6, R7, R21, R23, R25, R27, R29, R31, R33, R35, R37, R39, R41, R43, R45, R47, R49, R52: 470R; R_Axial_DIN0204_L3.6mm_D1.6mm_P5.08mm_Horizontal
R53: 330R; R_Axial_DIN0204_L3.6mm_D1.6mm_P5.08mm_Horizontal
U1: ESP32_DevKit_V4; esp32_devkit_v4
U2, U3: MCP23017_SP; DIP-28_W7.62mm

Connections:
+5V: R1.1, R2.1, R3.1, R4.1, R5.1, R6.1, R7.1, R8.1, R9.1, R10.1, R11.1, R12.1, R13.1, R14.1, R15.1, R16.1, R17.1, R18.1, R19.1, R20.1, R21.1, R23.1, R25.1, R27.1, R29.1, R31.1, R33.1, R35.1, R37.1, R39.1, R41.1, R43.1, R45.1, R47.1, R49.1, R52.1, R53.1, U1.19 (VIN), U2.9 (VDD), U3.9 (VDD), U3.15 (A0); also elsewhere on the board
/5V Supply/6V-24V: J1.2; also elsewhere on the board
Active: J5.50, U1.24 (IO2)
F0: J4.5, R20.2
F1: J4.11, R19.2
F2: J4.17, R18.2
F3: J4.23, R17.2
F4: J4.29, R16.2
F5: J4.35, R15.2
F6: J4.41, R14.2
F7: J4.47, R13.2
F8: J5.5, R12.2
F9: J5.11, R11.2
FA: J5.17, R10.2
FB: J5.23, R9.2
FC: J5.29, R8.2
FD: J5.35, R5.2
FE: J5.41, R4.2
FF: J5.47, R2.2
G0: J4.1, R52.2
G1: J4.7, R49.2
G2: J4.13, R47.2
G3: J4.19, R45.2
G4: J4.25, R43.2
G5: J4.31, R41.2
G6: J4.37, R39.2
G7: J4.43, R37.2
G8: J5.1, R35.2
G9: J5.7, R33.2
GA: J5.13, R31.2
GB: J5.19, R29.2
GC: J5.25, R27.2
GD: J5.31, R25.2
GE: J5.37, R23.2
GF: J5.43, R21.2
GND: J1.1, J2.1, J3.2, J3.4, R22.2, R24.2, R26.2, R28.2, R30.2, R32.2, R34.2, R36.2, R38.2, R40.2, R42.2, R44.2, R46.2, R48.2, R50.2, R51.2, U1.14 (GND), U1.32 (GND), U1.38 (GND), U2.10 (VSS), U2.15 (A0), U2.16 (A1), U2.17 (A2), U3.10 (VSS), U3.16 (A1), U3.17 (A2); also elsewhere on the board
unnamed: J2.2, R1.2, U1.5 (IO34)
unnamed: J3.1, R7.2, U1.27 (IO16)
unnamed: J4.49, R3.2
unnamed: J5.49, R53.2
unnamed: U1.28 (IO17), U2.18 (~RESET~), U3.18 (~RESET~)
O0: J4.6, U2.1 (GPB0)
O1: J4.12, U2.2 (GPB1)
O2: J4.18, U2.3 (GPB2)
O3: J4.24, U2.4 (GPB3)
O4: J4.30, U2.5 (GPB4)
O5: J4.36, U2.6 (GPB5)
O6: J4.42, U2.7 (GPB6)
O7: J4.48, U2.8 (GPB7)
O8: J5.6, U3.1 (GPB0)
O9: J5.12, U3.2 (GPB1)
OA: J5.18, U3.3 (GPB2)
OB: J5.24, U3.4 (GPB3)
OC: J5.30, U3.5 (GPB4)
OD: J5.36, U3.6 (GPB5)
OE: J5.42, U3.7 (GPB6)
OF: J5.48, U3.8 (GPB7)
R0: J4.4, R51.1
R1: J4.10, R50.1
R2: J4.16, R48.1
R3: J4.22, R46.1
R4: J4.28, R44.1
R5: J4.34, R42.1
R6: J4.40, R40.1
R7: J4.46, R38.1
R8: J5.4, R36.1
R9: J5.10, R34.1
RA: J5.16, R32.1
RB: J5.22, R30.1
RC: J5.28, R28.1
RD: J5.34, R26.1
RE: J5.40, R24.1
RF: J5.46, R22.1
SCL: U1.36 (IO22), U2.12 (SCK), U3.12 (SCK)
SDA: U1.33 (IO21), U2.13 (SDA), U3.13 (SDA)
SG0: J4.2, J4.3, U2.21 (GPA0)
SG1: J4.8, J4.9, U2.22 (GPA1)
SG2: J4.14, J4.15, U2.23 (GPA2)
SG3: J4.20, J4.21, U2.24 (GPA3)
SG4: J4.26, J4.27, U2.25 (GPA4)
SG5: J4.32, J4.33, U2.26 (GPA5)
SG6: J4.38, J4.39, U2.27 (GPA6)
SG7: J4.44, J4.45, U2.28 (GPA7)
SG8: J5.2, J5.3, U3.21 (GPA0)
SG9: J5.8, J5.9, U3.22 (GPA1)
SGA: J5.14, J5.15, U3.23 (GPA2)
SGB: J5.20, J5.21, U3.24 (GPA3)
SGC: J5.26, J5.27, U3.25 (GPA4)
SGD: J5.32, J5.33, U3.26 (GPA5)
SGE: J5.38, J5.39, U3.27 (GPA6)
SGF: J5.44, J5.45, U3.28 (GPA7)
Stop: J3.3, R6.2, U1.23 (IO15)
WiFi: J4.50, U1.26 (IO4)

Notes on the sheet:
Diodes + -
Green
Red
Yellow

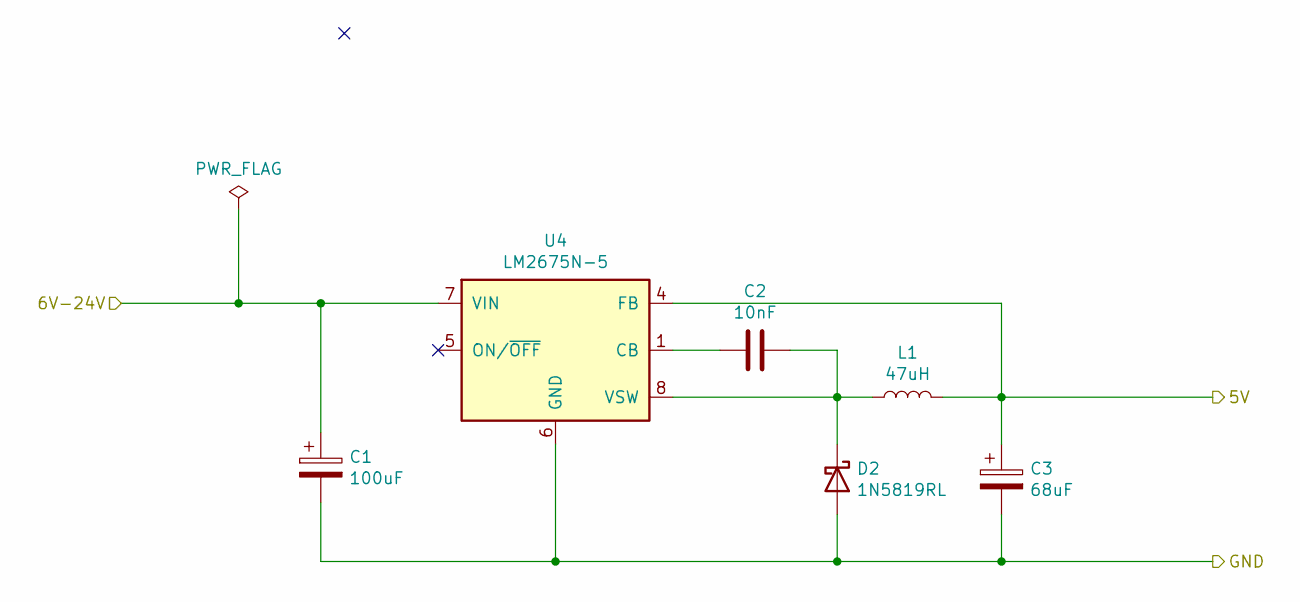
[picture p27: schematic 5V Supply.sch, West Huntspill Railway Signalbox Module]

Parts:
C1: 100uF; CP_Radial_D5.0mm_P2.00mm
C2: 10nF; C_Rect_L10.0mm_W4.0mm_P7.50mm_MKS4
C3: 68uF; C_Radial_D4.0mm_H7.0mm_P1.50mm
D2: 1N5819RL; D_DO-41_SOD81_P7.62mm_Horizontal
L1: 47uH; L_Toroid_Vertical_L14.7mm_W8.6mm_P5.58mm_Pulse_KM-1
U4: LM2675N-5; DIP-8_W7.62mm

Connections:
+5V: C3.1, L1.2, U4.4 (FB); also elsewhere on the board
/5V Supply/6V-24V: C1.1, U4.7 (VIN); also elsewhere on the board
GND: C1.2, C3.2, D2.2 (A), U4.6 (GND); also elsewhere on the board
unnamed: C2.1, D2.1 (K), L1.1, U4.8 (VSW)
unnamed: C2.2, U4.1 (CB)

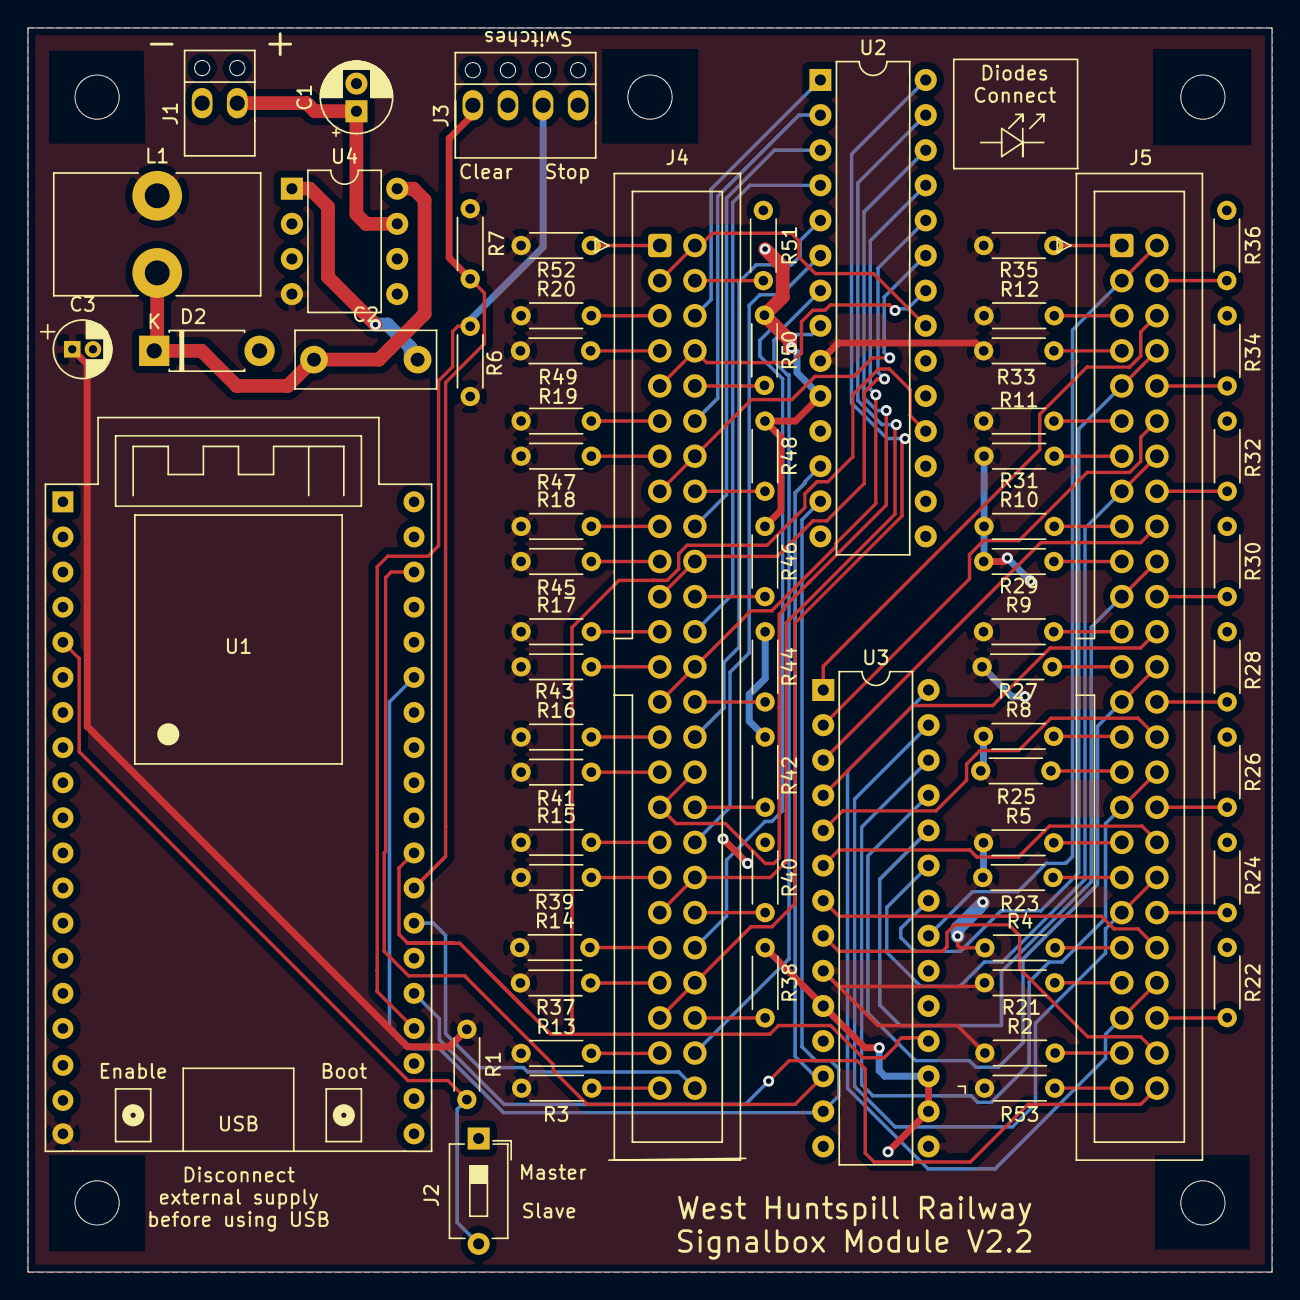
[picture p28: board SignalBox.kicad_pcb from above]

Board: 2 copper layers, 90.0 x 90.0 mm, 67 parts (0 on the bottom side), 95 nets.

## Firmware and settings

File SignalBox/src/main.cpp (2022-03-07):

#include <Arduino.h>

#include <myWiFi.h>
#include <WiFiUDP.h>
#include <Wire.h>
#include "myEEPROM.h"

#define softwareVersion 1.10

const int udpPort = 44444;
WiFiUDP udp;
uint8_t txBuffer[100] = "";
uint8_t rxBuffer[100] = "";
IPAddress lastIP;

uint8_t sensorStart[16] = {150, 150, 150, 150, 150, 150, 150, 150, 150, 150, 150, 150, 150, 150, 150, 150}; // default to 2m start (150cm + 50cm)
uint8_t sensorSpan[16] = {100, 100, 100, 100, 100, 100, 100, 100, 100, 100, 100, 100, 100, 100, 100, 100};  // default to 1m  span -> detection range from 2m to 3m

// IPAddress sensorAddress[16];

bool sensorActive[16] = {false, false, false, false, false, false, false, false, false, false, false, false, false, false, false, false};
bool seenActive[16] = {false, false, false, false, false, false, false, false, false, false, false, false, false, false, false, false};

hw_timer_t *fastTimer = NULL;
hw_timer_t *slowTimer = NULL;

// EEPROM
myEEPROM eeprom;

// defines variables
bool ledState;
bool detected;
bool sendAddress;
bool clearSensorActive;
bool clearPressed = false;
bool stopPressed = false;
bool isMaster;
bool eepromAvailable = false;

uint16_t portA;
uint16_t portB;

bool manualState[16] = {false, false, false, false, false, false, false, false, false, false, false, false, false, false, false, false}; // indicates manual stop switch is active

// int demoSteps = 7; // the default number of lights on the board for demo mode

#define wifiActive 4
#define signalsActive 2
#define stopButton 15
#define clearButton 16
#define master 34
#define uartReset 17
#define espReset

#define EEPROMtestaddr 32
#define EEPROMstartaddr 0
#define EEPROMspanaddr 128



void timerInterrupt()
{
  sendAddress = true;
}

void slowTimerInterrupt()
{
  clearSensorActive = true;
}

void writePortA(uint16_t value)
{
  Wire.beginTransmission(0x20); // first 23017
  Wire.write(0x12);             // Bank A
  uint8_t aByte = value & 0xff;
  Wire.write(aByte);
  Wire.endTransmission();
  Wire.beginTransmission(0x21); // second 23017
  Wire.write(0x12);             // Bank A
  aByte = value >> 8;
  Wire.write(aByte);
  Wire.endTransmission();
}

void writePortB(uint16_t value)
{
  Wire.beginTransmission(0x20); // first 23017
  Wire.write(0x13);             // Bank B
  uint8_t aByte = value & 0xff;
  Wire.write(aByte);
  Wire.endTransmission();
  Wire.beginTransmission(0x21); // second 23017
  Wire.write(0x13);             // Bank B
  aByte = value >> 8;
  Wire.write(aByte);
  Wire.endTransmission();
}

void ledRed(int sensor)
{
  uint16_t value = 0x0001 << sensor;
  // Serial.print("bit pattern:");
  // Serial.print(value, BIN);
  // Serial.print(" for sensor:");
  // Serial.println(sensor);
  Serial.print("RED on for sensor:");
  Serial.println(sensor);
  portA = portA | value;
  writePortA(portA);
}

void ledGreen(int sensor)
{
  uint16_t value = 0x0001 << sensor;
  value = value ^ 0xFFFF;
  // Serial.print("bit pattern:");
  // Serial.print(value, BIN);
  // Serial.print(" for sensor:");
  // Serial.println(sensor);
  Serial.print("GREEN on for sensor:");
  Serial.println(sensor);
  portA = portA & value;
  writePortA(portA);
}

void occupiedSection(int sensor)
{
  // turns on the yellow led to show train in section
  uint16_t value = 0x0001 << sensor;
  value = value ^ 0xFFFF;
  // Serial.print("bit pattern:");
  // Serial.print(value, BIN);
  // Serial.print(" for sensor:");
  // Serial.println(sensor);
  portB = portB & value;
  writePortB(portB);
  Serial.print("YELLOW on for track:");
  Serial.println(sensor);
}

void clearSection(int sensor)
{
  // turn off the yellow led to show the section is clear
  uint16_t value = 0x0001 << sensor;
  // Serial.print("bit pattern:");
  // Serial.print(value, BIN);
  // Serial.print(" for sensor:");
  // Serial.println(sensor);
  portB = portB | value;
  writePortB(portB);
  Serial.print("YELLOW off for track:");
  Serial.println(sensor);
}

bool compareBuffers(char *buf1, const char *buf2, int num)
{
  if (num == 0)
    return false;
  for (int i = 0; i < num; i++)
  {
    if (buf1[i] != buf2[i])
    {
      return false;
    }
    // Serial.print("buf1:");
    // Serial.print(buf1[i]);
    // Serial.print("  buf2:");
    // Serial.println(buf2[i]);
  }
  return true;
}

bool compareBuffersFrom(char *buf1, const char *buf2, int from, int num)
{
  if (num == 0)
    return false;

  // Serial.print("from:");
  // Serial.print(from);
  // Serial.print("  num:");
  // Serial.println(num);

  for (int i = from; i < (num + from); i++)
  {
    // Serial.print("buf1:");
    // Serial.print(buf1[i]);
    // Serial.print("  buf2:");
    // Serial.println(buf2[i - from]);
    if (buf1[i] != buf2[i - from])
    {
      return false;
    }
  }
  return true;
}

char *getUdpMessage()
{
  udp.parsePacket();
  rxBuffer[0] = 0;
  if (udp.read(rxBuffer, 50) > 0)
  {
    // received a message
    // Serial.print("getUdpMessage->Received: ");
    // Serial.println((char *)buffer);
    lastIP = udp.remoteIP();
  }
  return (char *)rxBuffer;
}

void copyToTxBuffer(const char *str)
{
  memcpy(txBuffer, str, strlen(str));
}

String binaryString(uint16_t value)
{
  char buffer[17] = "0000000000000000";
  for (int i = 0; i < 16; i++)
  {
    uint16_t test = 0x0001 << i;
    if (value & test)
    {
      // bit is a '1'
      buffer[i] = '1';
    }
  }
  return String(buffer);
}

void sendAddressMessage()
{
  // broadcast message to the signals sent every 500ms
  //                    led           Sensor setting
  //                    stat      start distance, span
  //                    |--||------------------------------|
  // "Signalbox Address:AaBb00112233445566778899aabbccddeeff255.255.255.255"
  //  0000000000111111111122222222223333333333444444444455555555556666666666
  //  0123456789012345678901234567890123456789012345678901234567890123456789
  //
  //  sensor start distance = 8bit value (cm) + 50 cm minimum offset
  //  sensor span distance = 8bit value (cm)

  static uint16_t lastPortA = 0;
  static uint16_t lastPortB = 0;
  if (isMaster)
  {
    //  This bradcasts the signalbox IP address if the signalbox is a master
    copyToTxBuffer("Signalbox Address: ");
    uint8_t aByte;
    aByte = portA >> 8;
    txBuffer[18] = aByte; // put in the bit pattern for the lights (bits 4-7)
    aByte = portA & 0xff;
    txBuffer[19] = aByte; // put in the bit pattern for the lights (bits 0-3)
    aByte = portB >> 8;
    txBuffer[20] = aByte; // put in the bit pattern for the lights (bits B-F)
    aByte = portB & 0xFF;
    txBuffer[21] = aByte; // put in the bit pattern for the lights (bits 8-A)

    // add the sensor settings
    for (int i = 0; i <= 15; i++)
    {
      txBuffer[22 + (i * 2)] = sensorStart[i];
      txBuffer[23 + (i * 2)] = sensorSpan[i];
    }

    const char *adr = WiFi.localIP().toString().c_str();
    int adrLen = strlen(adr);
    // Serial.println(adrLen);
    memcpy(&txBuffer[54], adr, adrLen);
    // Serial.println((char *)buffer);
    udp.beginPacket("255.255.255.255", udpPort);
    udp.write(txBuffer, 69);
    udp.endPacket();
    sendAddress = false;
    if (lastPortA != portA || lastPortB != portB)
    {
      String portAString = binaryString(portA);
      String portBString = binaryString(portB);
      Serial.print("Signalbox Address Broadcast with portA:");
      Serial.print(portAString);
      Serial.print(" portB:");
      Serial.println(portBString);
      lastPortA = portA;
      lastPortB = portB;
    }
  }
}

void actionTrainDetected(int sensorID)
{
  ledRed(sensorID);
  occupiedSection(sensorID);
}

void trackClear(int sensorID)
{
  int previousSensor = sensorID;
  bool searching = true;
  while (searching == true)
  {
    // Serial.print("Searching - ");
    previousSensor--;
    if (previousSensor < 0)
    {
      // Serial.print(" Wrapped to sensor 15");
      previousSensor = 15;
    }
    if (sensorActive[previousSensor] == true)
    {
      searching = false;
    }
    else
    {
      // Serial.print("sensor inactive ");
    }
  }
  // Serial.print("Clearing Track:");
  // Serial.println(previousSensor);
  if (manualState[previousSensor] == false && stopPressed == false)
  {
    // manual switch is not active so can change to Green
    ledGreen(previousSensor);
  }
  clearSection(previousSensor); // do clear the train from the previous section
}

// actions
void trainDetected(int sensorID)
{
  Serial.print("Train Detected Sensor:");
  Serial.println(sensorID);
  actionTrainDetected(sensorID);
}

void trackCleared(int sensorID)
{
  Serial.print("Track Cleared Sensor:");
  Serial.println(sensorID);
  trackClear(sensorID);
}

void manualStopPressed(int sensorID)
{
  // Serial.print("Sensor:");
  // Serial.print(sensorID);
  // Serial.println(" Manual Stop Activated");
  ledRed(sensorID); // indicate that the stop is on
  manualState[sensorID] = true;
}

void manualStopReleased(int sensorID)
{
  manualState[sensorID] = false;
  // check if we can clear the red led on the board
  // Serial.print("Sensor:");
  // Serial.print(sensorID);
  // Serial.println(" Manual Stop Released");
  uint16_t check = 0x0001 << sensorID;
  // Serial.print("check:");
  // Serial.print(check);
  // Serial.print(" portB:");
  // Serial.println(portB);
  if ((check & portB)) // portB pin low if train in section
  {
    // there is not a train in the section
    if (stopPressed == false)
    {
      // stop button not pressed so we can go back to green
      // Serial.println("Track clear so going Green");
      ledGreen(sensorID);
    }
  }
}

void forceTrackClear(int sensorID)
{
  // force clear of this sensors section of track (used for steaming bays)
  uint16_t check = 0x0001 << sensorID;
  portB = portB | check;
}

unsigned char checksum(char *ptr, size_t sz)
{
  unsigned char chk = 0;
  while (sz-- != 0)
    chk -= *ptr++;
  return chk;
}

void checkMessage()
{
  static uint16_t lastPortA = 0;
  static uint16_t lastPortB = 0;
  char *message = getUdpMessage();
  int messageLen = strlen(message);
  if (messageLen > 5)
  {
    //    Serial.print("checkSMessage->message: ");
    //    Serial.println(message);
    //    Serial.print("checkMessage->messageLen: ");
    //    Serial.println(messageLen);
    if (isMaster)
    {
      // this is a master so process the messages from sensors
      if (compareBuffers(message, "Sensor", 6))
      {
        // message from Sensor so update it's IP address in case it has changed
        int sensorID = message[7] - 48; // convert from ASCII
        // Serial.print("SensorID:");
        // Serial.println(sensorID);
        if (sensorID >= 0 && sensorID <= 15)
        {
          if (sensorActive[sensorID] == false)
          {
            Serial.printf("Aquired Sensor:%d running software %s\n", sensorID, &message[8]);
          }
          // sensorAddress[sensorID] = lastIP;
          sensorActive[sensorID] = true;
          seenActive[sensorID] = true; // indicate seen in this cycle
          // Serial.print("Seen Sensor:");
          // Serial.println(sensorID);
          digitalWrite(signalsActive, LOW); // turn on the signals active LED
        }

        // check for specific messages
        if (compareBuffersFrom(message, "Train Detected", 9, 13))
        {
          trainDetected(sensorID);
        }
        else if (compareBuffersFrom(message, "Track Clear", 9, 11))
        {
          trackCleared(sensorID);
        }
        else if (compareBuffersFrom(message, "Manual Stop Active", 9, 18))
        {
          manualStopPressed(sensorID);
        }
        else if (compareBuffersFrom(message, "Manual Stop Released", 9, 20))
        {
          manualStopReleased(sensorID);
        }
        else if (compareBuffersFrom(message, "Force Track Clear", 9, 17))
        {
          forceTrackClear(sensorID);
        }
        else
        {
          // Serial.println("Track occupied so staying Red");
        }
      }
      else if (compareBuffers(message, "Contrl", 6))
      {
        // It is a control message sent from the WHRApplication
        // config message format
        //        Imsc
        // Contrl:DDDs
        // 0000000000111111111122222222223
        // 0123456789012345678901234567890
        // ID = Sensor ID
        // mD = minDistance 1...250 (distance is + 50 cm)
        // sD = spanDistance 1...250 in cm
        // cs = checksum
        //
        // sensorStart and sensorSpan are the cm values for those attributes
        //        Serial.printf("Received message from WHRDisplay App %s\n", message);
        int sensorID = message[7] - 48; // convert from ASCII
        int ctrStart = message[8];
        int ctrSpan = message[9];
        Serial.printf("Received message from WHRDisplay App SensorID:%d minDistance:%d spanDistance:%d checkSum:%d\n", sensorID, ctrStart, ctrSpan, message[10]);
        //        int ctrCS = message[14];
        //        if (checksum(message, 10) == 0)
        //        {
        Serial.println("Checksum OK");
        // Serial.print("SensorID:");
        // Serial.println(sensorID);
        if (sensorID >= 0 && sensorID <= 15)
        { // a valid sensorID
          if (ctrStart != 255)
          {
            sensorStart[sensorID] = ctrStart;
            Serial.printf("new minDistance of %d for Sensor %d\n", ctrStart, sensorID);
          }
          if (ctrSpan != 255)
          {
            sensorSpan[sensorID] = ctrSpan;
            Serial.printf("new spanDistance of %d for Sensor %d\n", ctrSpan, sensorID);
          }
        }
        else
        {
          // check if it is all clear or all stop or all go
          if (sensorID == 35)
          {
            // All Stop
            portA = 0xffff;
          }
          if (sensorID == 40)
          {
            // All Clear
            portB = 0xffff;
          }
          if (sensorID == 23)
          {
            // all Go
            portA = 0;
          }
        }
        //       }
      }
    }
    else
    {
      // in slave mode so look for message from signal box
      if (compareBuffers(message, "Signalbox Address:", 18))
      {
        // process the light status
        uint8_t byte1 = message[18];
        uint8_t byte2 = message[19];
        uint16_t signalStates = byte1 << 8;
        signalStates = signalStates | byte2;
        byte1 = message[20];
        byte2 = message[21];
        uint16_t trackStates = byte1 << 8;
        trackStates = trackStates | byte2;
        portA = signalStates;
        portB = trackStates;
        writePortA(portA);
        writePortB(portB);
        if (lastPortA != portA || lastPortB != portB)
        {
          Serial.print("portA:");
          Serial.print(binaryString(portA));
          Serial.print("  portB:");
          Serial.println(binaryString(portB));
          lastPortA = portA;
          lastPortB = portB;
        }
      }
    }
  }
}

void checkMaster()
{
  if (digitalRead(master) == isMaster)
  {
    isMaster = !digitalRead(master); // switch is low for master High for Slave
    if (isMaster)
    {
      Serial.println("Configured as Master");
    }
    else
    {
      Serial.println("Configured as Slave");
    }
  }
}

void checkSwitches()
{
  checkMaster();
  if (isMaster)
  {
    if (digitalRead(clearButton) == false)
    {
      if (clearPressed == false)
      {
        // Serial.println("Clear button Pressed");
        if (stopPressed == false)
        {
          clearPressed = true;
          // clear all trains from board if the stop button is not pressed
          for (int i = 0; i < 16; i++)
          {
            clearSection(i);
            ledGreen(i);
          }
        }
      }
    }
    else
    {
      clearPressed = false;
    }
    if (digitalRead(stopButton) == false)
    {
      // stop button is pressed
      if (stopPressed == false)
      {
        // it wasn't pressed before
        // Serial.println("Stop button pressed");
        stopPressed = true;
        for (int i = 0; i < 16; i++)
        {
          // turn all the lights to red
          ledRed(i);
        }
      }
    }
    else
    {
      // stop button not pressed
      if (stopPressed == true)
      {
        // button just released
        stopPressed = false;
        for (int i = 0; i < 16; i++)
        {
          uint16_t check = 0x0001 << i;
          // Serial.print("check:");
          // Serial.print(check);
          // Serial.print(" portB:");
          // Serial.println(portB);
          if ((check & portB)) // portB pin low if train in section
          {
            // there is not a train in this section
            // stop button not pressed so we can go back to green
            // Serial.println("Track clear so going Green");
            ledGreen(i);
          }
        }
      }
    }
  }
}

void demoFlash(int pulses)
{
  static bool ledState = HIGH;
  for (int j = 0; j < pulses; j++)
  {
    ledState = !ledState;
    if (ledState == false)
    {
      digitalWrite(signalsActive, HIGH);
    }
    else
    {
      digitalWrite(signalsActive, LOW);
    }
    delay(500);
  }
}

void demoMode(void)
{
  // Demo mode
  stopPressed = false;
  if (!digitalRead(clearButton) && !digitalRead(stopButton))
  {
    // hold down clear and stop buttons to enter test mode
    int i = 0;
    Serial.println("Demo Mode");
    sensorActive[i] = true;
    writePortA(portA);
    writePortB(portB);
    sendAddressMessage();
    while (!digitalRead(stopButton)) // demo will run as long as stop is pressed
    {
      // make a train travel around the track
      actionTrainDetected(i); // simulate having received a train detected message from sensor i
      sendAddressMessage();
      demoFlash(3);
      if (!digitalRead(clearButton))
      {
        // hold down the clear button until the final section of track shows occupied
        sensorActive[i + 1] = true;
      }
      trackClear(i); // simulate having received a train clear messagefrom sensor i
      sendAddressMessage();
      demoFlash(10);
      i++;
      if (sensorActive[i] == false)
      {
        i = 0;
      }
    }

    for (i = 0; i < 16; i++)
    {
      // clear the demo mode sensors active flags
      sensorActive[i] = false;
    }
    portA = 0x0000;
    portB = 0XFFFF;
    writePortA(portA);
    writePortB(portB);
  }
}

void initUART()
{
  // setup the i2C UART
  portA = 0x0000;
  portB = 0XFFFF;

  digitalWrite(uartReset, LOW);
  delay(100);
  digitalWrite(uartReset, HIGH);
  delay(100);

  Wire.begin();
  Wire.beginTransmission(0x20);
  Wire.write(0x00); // IODIRA
  Wire.write(0x00); // All output
  Wire.endTransmission();

  Wire.beginTransmission(0x20);
  Wire.write(0x01); // IODIRB
  Wire.write(0x00); // All output
  Wire.endTransmission();

  Wire.beginTransmission(0x21);
  Wire.write(0x00); // IODIRA
  Wire.write(0x00); // All output
  Wire.endTransmission();

  Wire.beginTransmission(0x21);
  Wire.write(0x01); // IODIRB
  Wire.write(0x00); // All output
  Wire.endTransmission();

  writePortA(0xFFFF); // all red LED on
  writePortB(0xFFFF); // all yellow LED off
}
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
void loop()
{

  checkMaster();
  checkMessage();
  checkSwitches();

  if (WiFi.status() == WL_CONNECTED) {
      digitalWrite(wifiActive, LOW);    // turn on the wifi active LED
  } else {
      digitalWrite(wifiActive, HIGH);    // turn off the wifi active LED
  }

  if (sendAddress == true) // set true by teh fast timer interrupt every 0.5 seconds
  {
    sendAddressMessage();
  }
  if (clearSensorActive == true) // set true by the slow timer interrupt every 20 seconds
  {
    saveSettings();
    for (int i = 0; i < 16; i++)
    {
      if (seenActive[i] == false && sensorActive[i] == true)
      {
        // didn't see it last time
        sensorActive[i] = false; // show this sensor has is no longer active
        Serial.print("Lost Sensor:");
        Serial.println(i);
      }
      seenActive[i] = false; // clear the sensors (they will repopulate on next receipt of message)
    }
    clearSensorActive = false;
  }
}

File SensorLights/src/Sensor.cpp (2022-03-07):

#include <Arduino.h>
#include <myWiFi.h>
#include <WiFiUDP.h>

#define softwareVersion 1.20
int minDistance = 50;          // Minimum distance to trigger sensor in cm
int maxDistance = 100;         // Maximum distance to trigger sensor in cm
#define debounceThreshold 40   // Howmany times to see the sensor active before operating
#define retriggerThreshold 100 //  How many times to see the sensor inactive to enable re trigger
#define messageRepeat 3        // define how many times to repreat a message

const char *signalboxAddress = "255.255.255.255"; // ensure the storage is large enough
const int udpPort = 44444;
const char *payload[20];
WiFiUDP udp;
uint8_t txBuffer[150] = "";
uint8_t rxBuffer[150] = "";

#define echoPin 27     // Echo of HC-SR04
#define trigPin 26     // Trig of HC-SR04
#define sensedPin 18   // LED to show when sensor has detected
#define activePin 17   // LED to show when there is an active signalbox
#define wifiPin 16     // LED to indicate connected to WiFi
#define output1Pin 5   // output 1 (MOSFET high current)
#define output2Pin 4   // output 2 (MOSFET high current)
#define manualStop 15  // input for manual stop button (used at station)
#define sensorStart 36 // ADC input for sensor start distance
#define sensorSpan 39  // ADCinput for sensor span distance

#define localStop 14   // high if using standard stop button, low for forced stop button (clears train on release)
#define localSense 13  // high if using local sensor settings, low if using remote sensor settings
#define joinWiFiHub 25 // high is connecting to wifi network (low then create the network)

#define addb0 32 // address lines to set sensorID
#define addb1 33
#define addb2 34
#define addb3 35

// defines variables
long duration; // variable for the duration of sound wave travel
int distance;  // variable for the distance measurement
uint8_t sensorID;
bool ledState;
bool detected;
int debounce;
long retrigger;
bool haveSignalboxAddress;
bool manualStopActive = false;
bool autoStopActive = false;
bool myTrack = false;

bool remoteSettings = false;
bool forcedStopButton = false;
bool localWiFi = true;

hw_timer_t *timer = NULL;
bool sendAlive = false;
bool flashing = false;

void timerInterrupt()
{
  sendAlive = true;
}

uint8_t getSensorID()
{
  uint8_t iD = 0;
  if (digitalRead(addb0) == true)
  {
    iD = iD + 1;
  }
  if (digitalRead(addb1) == true)
  {
    iD = iD + 2;
  }
  if (digitalRead(addb2) == true)
  {
    iD = iD + 4;
  }
  if (digitalRead(addb3) == true)
  {
    iD = iD + 8;
  }
  return iD;
}

void readConfig()
{
  if (digitalRead(localStop) && forcedStopButton == true)
  {
    forcedStopButton = false;
    Serial.println("Standard stop button");
  }
  if (digitalRead(localStop) == false && forcedStopButton == false)
  {
    forcedStopButton = true;
    Serial.println("Forced clear stop Button");
  }
  if (digitalRead(localSense) && remoteSettings == true)
  {
    remoteSettings = false;
    Serial.println("Uses local sensor adjust values");
  }
  if (digitalRead(localSense) == false && remoteSettings == false)
  {
    remoteSettings = true;
    Serial.println("Uses Remote sensor adjust");
  }
  if (digitalRead(joinWiFiHub) == false && localWiFi == false)
  {
    localWiFi = true;
    Serial.println("provided local WiFi");
  }
  if (digitalRead(joinWiFiHub) == true && localWiFi == true)
  {
    localWiFi = false;
    Serial.println("joins remote WiFi");
  }
}

void setup()
{
  pinMode(trigPin, OUTPUT); // Sets the trigPin as an OUTPUT
  pinMode(echoPin, INPUT);  // Sets the echoPin as an INPUT
  pinMode(sensedPin, OUTPUT);
  pinMode(activePin, OUTPUT);
  pinMode(wifiPin, OUTPUT);
  pinMode(output1Pin, OUTPUT);
  pinMode(output2Pin, OUTPUT);
  pinMode(manualStop, INPUT_PULLUP);
  pinMode(addb0, INPUT_PULLUP);
  pinMode(addb1, INPUT_PULLUP);
  pinMode(addb2, INPUT_PULLUP);
  pinMode(addb3, INPUT_PULLUP);
  pinMode(localStop, INPUT_PULLUP);
  pinMode(localSense, INPUT_PULLUP);
  pinMode(joinWiFiHub, INPUT_PULLUP);
  pinMode(sensorStart, INPUT);
  pinMode(sensorSpan, INPUT);
  digitalWrite(sensedPin, HIGH);
  digitalWrite(activePin, HIGH);
  digitalWrite(wifiPin, HIGH);
  digitalWrite(output1Pin, LOW);
  digitalWrite(output2Pin, LOW);
  delay(1000);
  // read device address
  sensorID = getSensorID();

  delay(2000);          // let the debugger switch windows
  Serial.begin(115200); // // Serial Communication is starting with 115200 of baudrate speed
  Serial.println("");
  if (digitalRead(joinWiFiHub) == true)
  {
    Serial.print("West Huntspill Railway Sensor Module activated with ID:");
  }
  else
  {
    Serial.print("West Huntspill Railway Sensor Module and WiFi Hub activated with ID:");
  }
  Serial.println(sensorID);
  Serial.printf("Software Version: %.2f\n", softwareVersion);

  remoteSettings = digitalRead(localSense);  // force the read config to update first time
  forcedStopButton = digitalRead(localStop); // force the read config to update first time
  localWiFi = digitalRead(joinWiFiHub);
  readConfig();

  debounce = 0;
  detected = false;
  retrigger = 0;
  if (digitalRead(joinWiFiHub) == true)
  { // join the wifi network
    setupWiFi();
  }
  else
  {
    createWiFi();
   }
  digitalWrite(wifiPin, LOW); // indicate we are connected to WiFi
  haveSignalboxAddress = false;

  udp.begin(udpPort);
  Serial.println("Waiting for Signalbox Address");
  flashing = false;

  sendAlive = false;
  timer = timerBegin(0, 80, true);
  timerAttachInterrupt(timer, &timerInterrupt, true);
  timerAlarmWrite(timer, 10000000, true); // 1 second timer interrupt
  timerAlarmEnable(timer);
  sensorID = getSensorID();
}

String binaryString(uint16_t value)
{
  char buffer[17] = "0000000000000000";
  for (int i = 0; i < 16; i++)
  {
    uint16_t test = 0x0001 << i;
    if (value & test)
    {
      // bit is a '1'
      buffer[i] = '1';
    }
  }
  return String(buffer);
}

bool compareBuffers(char *buf1, const char *buf2, int num)
{
  if (num == 0)
    return false;
  for (int i = 0; i < num; i++)
  {
    if (buf1[i] != buf2[i])
    {
      return false;
    }
    // Serial.print("buf1:");
    // Serial.print(buf1[i]);
    // Serial.print("  buf2:");
    // Serial.println(buf2[i]);
  }
  return true;
}

char *getUdpMessage()
{
  udp.parsePacket();
  rxBuffer[0] = 0;
  if (udp.read(rxBuffer, 69) > 0)
  {
    // received a message
    // Serial.print("getUdpMessage->Received: ");
    // Serial.println((char *)buffer);
  }
  return (char *)rxBuffer;
}

void copyToTxBuffer(const char *str)
{
  memcpy(txBuffer, str, strlen(str) + 1);
}

void copyToBuffer(char *theBuffer, const char *str)
{
  memcpy(theBuffer, str, strlen(str) + 1);
}
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

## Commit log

2021-08-18 Corrected bug in SignalBox slave mode. Had used the master/slave pin define rather than reading the pin...
    [main.cpp]
2021-08-18 added potentiometers for setting of the sensor distance
    [SensorLights.sch]
2021-08-18 Fixed significant issue with light control. A } had got displaced. Added some debug to the signalbox to help find the problem
    [Sensor.cpp, main.cpp]
2021-08-27 Added functionality to the Stop button to support forced track clearing on release of Stop Button. This is to enable use at the Steaming bays where a train is removed from the tracks. Releasing the s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
2021-09-09 Added supportng files such as the face plate art work (including the image files for the iOS and macOS assets). Some CAD files for 3D models used during the development. Added a feature to flash the 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
    [SensorLights-B_Cu.gbr, SensorLights-B_Mask.gbr, SensorLights-B_Paste.gbr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]
2022-03-07 Added support for remote configuration ussing EEPROM in Signalbox. Supports companion application for iOS, macOS and watchOS to configure and control the lights remotely.
    [SensorLights.xlsx]

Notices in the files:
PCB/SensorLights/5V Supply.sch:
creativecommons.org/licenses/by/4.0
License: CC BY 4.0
